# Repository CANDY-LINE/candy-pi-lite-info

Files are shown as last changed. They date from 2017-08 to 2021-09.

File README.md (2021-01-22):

# CANDY Pi Lite/CANDY Pi Lite+ 利用ガイド

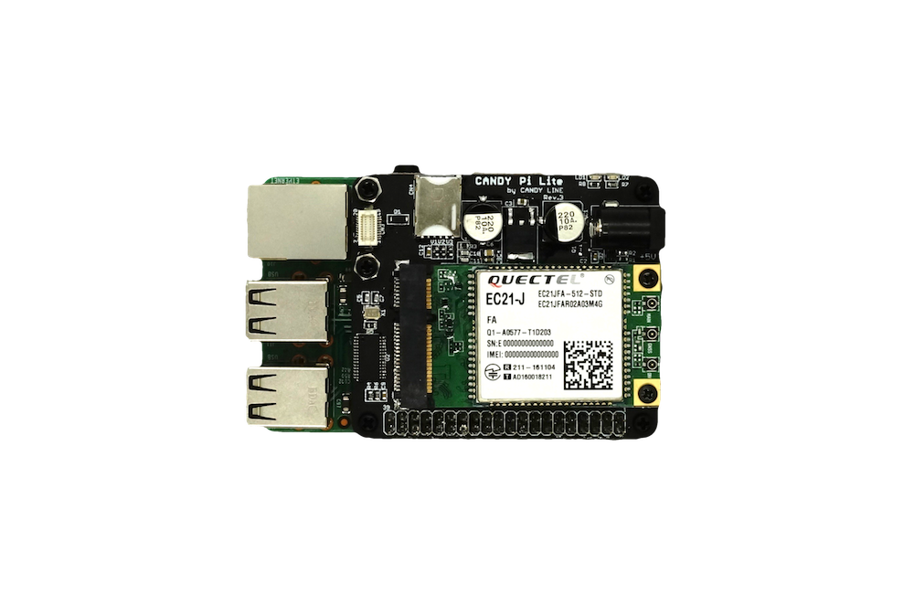
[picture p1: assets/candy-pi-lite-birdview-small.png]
CANDY Pi Lite with Raspberry Pi


CANDY Pi Lite及びCANDY Pi Lite+（以降、CANDY Pi Lite/+と表記します）は、Raspberry Pi（ラズベリーパイ、以下ラズパイ）や、ASUS Tinker Board(またはS)に取り付けて使用する3G/4G LTE通信ボードです。

CANDY Pi Lite 3Gモデルでは、3G回線をご利用頂けます（日本国外では2G及び3G回線をご利用いただけます）。CANDY Pi Lite LTEモデルでは、4G LTE回線をご利用頂けます。CANDY Pi Lite LTE-Mモデルでは、LTE-M回線、NB-IoT回線をご利用頂けます（日本国外では2G回線もご利用いただけます）。

CANDY Pi Lite+ Dモデルでは、NTTドコモの3G/4G LTE回線をご利用いただけます。CANDY Pi Lite+ Kモデルでは、au/KDDIの4G LTE回線とNTTドコモの3G/4G LTE回線をご利用いただけます。CANDY Pi Lite+ Sモデルでは、Softbankの3G/4G LTE回線をご利用いただけます。

CANDY Pi Lite+（マルチキャリア版）モデルでは、NTTドコモの3G/4G LTE回線、au/KDDIの4G LTE回線、それにSoftbankの3G/4G LTE回線をご利用いただけます。

本書では、CANDY Pi Lite/+の利用方法について、組立方法、利用開始までのセットアップ方法、また製品の外寸などのハードウェア情報を解説します。CANDY Pi Lite/+の活用方法やチュートリアルについては、[CANDY LINE Blog](https://candy-line.com/blog/) をご覧ください。

CANDY Pi Lite/+とそのサービスソフトウェア(candy-pi-lite)は、標準でPPPと呼ばれる方式で携帯電話ネットワークへ接続します。CANDY Pi Lite/+に搭載している通信モジュールは、Qualcomm Modem Interface(QMI)に対応しているため、USB接続で利用された場合は、QMI WWANを利用して通信を行うことも仕様上は可能です。しかし、今のところcandy-pi-lite サービスではQMI WWANに対応していません。

# 本書について

本書の内容は、随時加筆修正が行われます。最終更新日をご確認ください。

# 法律とライセンス

本書の著作権は、株式会社 CANDY LINEが保有しています。
本書の文章や写真等イメージデータの内容は、[CC-BY-NC-SA 4.0](https://creativecommons.org/licenses/by-nc-sa/4.0/)ライセンスの下で公開されます。

- 「CANDY Pi」、「CANDY LINE」は、株式会社 CANDY LINEの商標または登録商標です。
- 「Raspberry Pi」はRaspberry Pi財団の登録商標です。
- 「ASUS」は、ASUSTek Computerの登録商標です。
- 「Bluetooth」は、Bluetooth SIG,Inc.の登録商標です。
- 「EnOcean」は、EnOcean GmbHの登録商標です。
- その他の名称は、それぞれの所有者の商標または登録商標です。

その他、本書に記載されている製品名や会社名は、各企業の登録商標あるいは商標です。本文中では、「™」「®」マークが明記されていないことがあります。

# CANDY Pi Lite/+の使用について

⚠️CANDY Pi Lite/+の使用については、以下の点を注意してください。

1. **CANDY Pi Lite/+を水に濡らしたり、湿度の高いところで利用したり、あるいはまた結露が発生するような状況で利用しないようにしてください。**
1. **CANDY Pi Lite/+のDCジャックは、最大4Aまで対応しています。それより大きい電流容量のACアダプターを利用しないようにしてください。**
1. **CANDY Pi Lite/+のDCジャックは、初期ロットのASUS Tinker Board Sでは動作しないためお使いいただけません。2018年3月下旬以降に出荷されたASUS Tinker Board Sではご利用いただけます。**
1. **CANDY Pi Lite LTEモデルとCANDY Pi Lite+は、日本国内専用です。日本国外では利用してはいけません。**
1. **CANDY LINE®がインターネットで公開している情報以外の3G/4G LTE通信モデムに関する情報については、[リファレンス](references.md)ページ記載のメーカー情報をご覧ください。**

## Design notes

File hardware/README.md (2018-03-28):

# ハードウェア

ハードウェアに関する情報は、以下のページでご覧いただけます。

* [定格](rating.md)
* [寸法](size.md)
* [本体基板外観](appearance.md)
* [GPIOピンマッピング](gpio.md)
* [交換部品](supplies.md)
* [ASUS Tinker Board 付属のヒートシンクをお使いの方へ](atb-heatsink.md)

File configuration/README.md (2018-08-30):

# 設定変更

candy-pi-lite サービスについて以下の設定について説明します。

* [LED設定](led.md)
* [APN設定](apn.md)
* [モバイルネットワークへの接続設定](connection.md)
* [プリセットされたAPNの一覧](apn-list.md)
* [GNSS/GPSの使用](gnss.md)
* [自動時刻調整](rtc.md)
* [有線LAN固定IP設定](ether-static-ip.md)
* [ハードウェアWatchdog](hw-watchdog.md)
* [EnOcean USBゲートウェイの利用](enocean.md)
* [デフォルトゲートウェイ調整機能のOFF](default-gw-adjuster.md)
* [シリアルポートの種別選択指定](serial-port-selector.md)
* [ufwを利用してグローバルIP経由のPingを拒否する方法](ufw-icmp.md)
* [RaspberryPi(Raspbian)でモバイルルーターとして使用する設定](rpi-router.md)
* [利用可能なシリアルポートについて](serialports.md)
* [IP到達確認監視](ip-reachability-test.md)

また、CANDY REDの下記設定方法についても説明します。

* [ノードの設定](candy-red-nodes.md)

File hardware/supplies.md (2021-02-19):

<!-- toc -->

# 追加部品、交換部品

## USBケーブル

USB接続をご利用の場合、ご利用者の方にUSBケーブルをご用意いただく必要があります。USBケーブルは電源を供給する必要はないため、多くの場合コネクターの形状があっていれば現在流通するケーブルを利用可能です。仕様上はUSB2.0の規格を満たしていればそれ以外の要件はありません。

個人利用であれば、充電専用ではないものであれば100円ショップのものでも利用可能ですし、大量に使用する場合は、下記のような商品をご利用ください。

- [USBケーブル（秋月電子通商）](http://akizukidenshi.com/catalog/c/cusbcable/)
- [USBケーブル（せんごくネット通販）](https://www.sengoku.co.jp/mod/sgk_cart/search.php?cid=3684)

ご購入の際は、USBケーブルのコネクターの形状にご注意ください。

- USBタイプAオス・・・「Raspberry Pi Model A+/Model B+/Pi2/Pi3」「ASUS Tinker Board」側
- マイクロUSB(マイクロB)オス・・・「CANDY Pi Lite」「CANDY Pi Lite+」接続側（「なにつなぐ？」ボード側）、「Raspberry Pi Zero/W/WH」側

\* Raspberry Pi Zero/W/WH」をご利用の場合、希望のケーブルがないときは変換コネクターもご利用いただけます。

## アンテナとSMA-U.FL変換ケーブルセット

「CANDY Pi Lite 3G」、「CANDY Pi Lite LTE」、「CANDY Pi Lite+ D」、「CANDY Pi Lite+ S」、「CANDY Pi Lite+ K」に付属しているアンテナとケーブルは、ソラコム社のコンソールから購入が可能です。

- メーカー：Hanwool Technology
- 型名：HW-MULTI-GA-RSMA
- 紹介サイト：https://soracom.jp/products/module/

アカウントを作成してから（無料）、管理コンソールの画面を通じて購入が可能です。
購入方法の詳細については、「[お問い合わせ](https://soracom.jp/contact/)」ページより直接ソラコム社へお問い合わせください。

## SMA-U.FL変換ケーブル

通信モジュールとアンテナとを取り付ける同軸ケーブルには、SMAとU.FLコネクターの変換ケーブルを利用しています。
このケーブルはSMAの根元部分や、U.FLの根元部分は取り外しのタイミングで破損しやすいため、取り扱いにはご注意ください。

ケーブルの取り外しの際には、指だけで取り外すとコネクターの根元を破損しやすいため、先がL字型のピンセットのようなものを使って以下の写真のようにしっかり掴んでから垂直に引っ張るようにすると安全に取り外しができます。

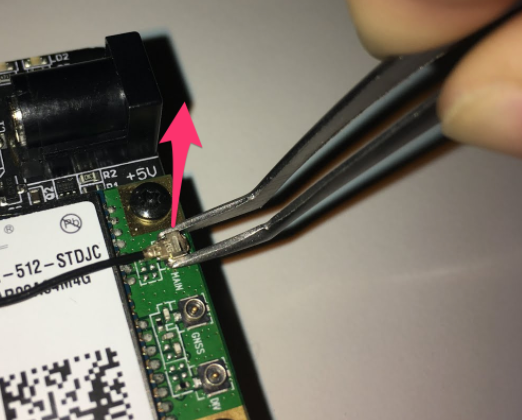
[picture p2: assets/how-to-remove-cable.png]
ケーブル取り外し


なおもし以下の写真のように破損してしまった場合は、下記の商品にて代用可能です（SMAコネクターの部分がリバースタイプではないもの）。

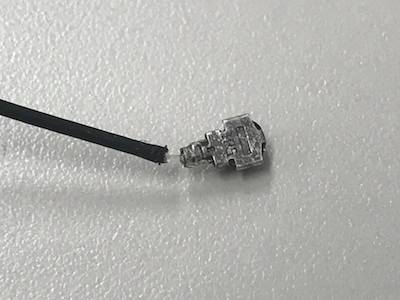
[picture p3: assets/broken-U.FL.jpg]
U.FL破損部分


- [SMA-U.FL変換ケーブル 長さ約10cm(せんごくネット通販)](http://www.sengoku.co.jp/mod/sgk_cart/detail.php?code=2DC5-UHLE)
- [RS Pro, 同軸ケーブルアセンブリ 150mm(アールエスコンポーネンツ)）](http://jp.rs-online.com/web/p/coaxial-cable-assemblies/7942897/)

## GNSS/GPSアンテナ・ケーブル

「CANDY Pi Lite 3G」と「CANDY Pi Lite+」については、GNSSモジュールが搭載されています。このモジュールを使うためには、専用のアンテナをご利用ください。付属のアンテナでも利用可能ですがケーブル長がほぼないため、常にラズパイを屋外か屋外近くに配置する必要があり実用的ではありません。

SMAコネクター接続のGNSS/GPSアンテナをご利用いただくとケーブルの取り回しがしやすく便利です。
なお、同軸ケーブルについては、付属品では足りない場合は上記SMAケーブルをご利用ください。

## DCジャック用ACアダプター

「CANDY Pi Lite 3G」、「CANDY Pi Lite LTE」や「CANDY Pi Lite+」に搭載されているDCジャックは、以下の規格に合致したACアダプターを利用することが可能です。

- 出力電圧：5V
- 出力電流：3Aまたは4A（Raspbrry PiやASUS Tinker Boardに取り付ける機器も加味してご検討ください）
- プラグ形状：DCプラグ・ジャック
- プラグ寸法：内径：φ2.1mm、外径：φ5.5mm
- 極性：センタープラス

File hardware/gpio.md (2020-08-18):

<!-- toc -->

# GPIOピンマッピング

CANDY Pi Lite/CANDY Pi Lite+は以下のGPIOピンを使用しています。

GPIOをお使いの場合は、下記以外のピンをご利用ください。

| GPIO HW Pin#  | RPi GPIO(40pins) | ASUS Tinker Board(またはS) | UC20/EC21 | CANDY Pi Lite |
| --- | --- | --- | --- | --- |
| PIN 38 |  20 (OUT) |  187 (OUT, GP6A3) | PERESET | RESET |
| PIN 32 |  12 (OUT) |  239 (OUT, GP7C7) | W_DISABLE | - |
| PIN 19 |  10 (SPI0_MOSI)  |  257 (SPI2TXD, GP8B1)  | - | SI |
| PIN 21 | 9 (SPI0_MISO)  |  256 (SPI2RXD, GP8B0)  | - | SO |
| PIN 23 |  11 (SPI0_SCLK)  |  254 (SPI2CLK, GP8A6)  | - | SCLK |
| PIN 26 | 7 (SPI0_CE1) |  251 (SPI2CSN1, GP8A3) | - | CS |
| PIN 40 |  21 (IRQ) |  188 (IRQ, GP6A4) | - | IRQ |
| - | - | - | LED_WWAN |  LED1 (GREEN) |
| PIN  7 | 4 (OUT) |  17 (OUT, GP0C1) | - |  LED2 (ORANGE)|

## SPI接続について

本製品は、ラズパイやASUS Tinker Boardの40ピンGPIOにあるSPIを使用しています。ラズパイでは、`SPI0`を、ATBでは`SPI2`を使用します。ラズパイでもASUS Tinker Boardでもチップセレクト1(`CE1`/`CS1`)を物理的に常に占有していますので、SPIをお使いになる場合は、チップセレクト0(`CE0`/`CS0`)のピンをご利用ください。`CE1`/`CS1`を利用することはできませんのでご注意ください。

Raspberry Pi B+以降で使用できる`SPI1`については、残念ながら本製品の使用するGPIOピンが一部重複しているため使用できません。

ASUS Tinker Boardの`SPI0`については、ピンが重複していないため利用可能です。

## LED2（オレンジ）

candy-pi-liteの動作状況を表します。一定パターンで点滅を繰り返しているときは、携帯電話ネットワークに接続されています。消灯の場合は、携帯電話ネットワークへ接続できていません。

## PERST（リセット）

PERSTをlowに落とすと、3G/LTE通信モジュールとCANDY Pi Lite上のSC16IS75xのチップの両方をリセットすることができます。lowに落とす時間は、UC20/EC21の技術資料(Hardware Design)によれば、150~460msと決められていますが、概ね1秒程度でもリセット可能です。

candy-pi-lite サービスでは、サービス起動時にモデムのリセットを常に行なっていますので、通常の利用であれば利用者の方が明示的にリセットを行う必要はありません。

## W_DISABLE（無線OFF）

W_DISABLEピンをlowに落とすと、3G/LTE通信モジュールの無線動作を止めることができます。ただし、この操作をして無線を停止した場合、candy-pi-lite サービスが接続できないことを検出するまでおよそ2~3分かかります。

通常は、candy-pi-lite サービスの停止によって通信を停止するようにしてください。

なお、W_DISABLEピンをhighに設定し直したとしても、通信が自動的に復帰することはありません。明示的に[candy-pi-lite サービスを再起動](/service/restart.md)してください。また、無線接続を再開する場合は、W_DISABLEピンをhighに設定し直す必要がありますが、candy-pi-lite サービスは自動的に再設定を行いますので、利用者の方がW_DISABLEピンをhighに戻す必要はありません。

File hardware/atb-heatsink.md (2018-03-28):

<!-- toc -->

# ASUS Tinker Board 付属のヒートシンクをお使いの方へ

ASUS Tinker BoardやASUS Tinker Board Sには、標準でヒートシンクが付属しています。このヒートシンクを取り付けた時、CANDY Pi Lite付属のスペーサーでは高さが足りず、CANDY Pi Liteの本体基板と接触します。このため、以下の対応をお願いいたします。

* ネジ径2.6ミリ、長さ12ミリまたはそれより長いスペーサー（例えば、[樹脂スペーサー](http://www.hirosugi-net.co.jp/shop/g/g4210/)や[金属スペーサー](http://www.hirosugi-net.co.jp/shop/g/g416/)など）をご購入いただく（付属品は長さ11ミリです）。

上記対応により、CANDY Pi Lite取り付け時にGPIOピン接触部分が1ミリ浮き上がりますが動作に支障はございません。

## スペーサー配布プログラムにつきまして

CANDY LINEでは、ユーザー登録をされた方でご希望の方には、一定条件を満たすと2018年3月31日（日本時間）まで真鍮製12ミリスペーサー（1台あたり4本）を無償で郵送するプログラムを実施します。詳しい適用条件は、[こちらの案内](https://forums.candy-line.io/t/topic/128)をご覧ください。

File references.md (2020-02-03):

# リファレンス

CANDY Pi Liteに搭載されている3G/LTE通信モジュールの技術情報については以下の情報を参照してください。通信モジュールそのものに関する質問等は、[Quectel Wireless Solutions社の技術フォーラム](https://forums.quectel.com/)をご利用ください。

- [Quectel Wireless Solutions UC20 仕様](http://www.quectel.com/product/uc20minipcIe.htm)
- [Quectel Wireless Solutions EC21 仕様](http://www.quectel.com/product/ec21minipcIe.htm)
- [Quectel Wireless Solutions EC25 仕様](http://www.quectel.com/product/ec25minipcIe.htm)
- [Quectel Wireless Solutions BG96 仕様](https://www.quectel.com/product/bg96.htm)
- [Quectel Wireless Solutions UC20 技術ドキュメントのダウンロード](http://www.quectel.com/support/downloadb/TechnicalDocuments.htm?keys=UC20)
- [Quectel Wireless Solutions EC21 技術ドキュメントのダウンロード](http://www.quectel.com/support/downloadb/TechnicalDocuments.htm?keys=EC21)
- [Quectel Wireless Solutions EC25 技術ドキュメントのダウンロード](http://www.quectel.com/support/downloadb/TechnicalDocuments.htm?keys=EC25)
- [Quectel Wireless Solutions BG96 技術ドキュメントのダウンロード](http://www.quectel.com/support/downloadb/TechnicalDocuments.htm?keys=BG96)

**ご注意：上記のうち、技術ドキュメントのダウンロードにはユーザー登録が必要となります。ユーザー登録の案内はPDFダウロード時に表示されます。**

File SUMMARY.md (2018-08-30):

# Summary

* [はじめに](README.md)
* [ハードウェア情報](hardware/README.md)
  * [定格](hardware/rating.md)
  * [寸法](hardware/size.md)
  * [本体基板外観](hardware/appearance.md)
  * [GPIOピンマッピング](hardware/gpio.md)
  * [交換部品](hardware/supplies.md)
  * [ASUS Tinker Board 付属のヒートシンクをお使いの方へ](hardware/atb-heatsink.md)
* [セットアップの仕方](setup/README.md)
  * [CANDY Pi Lite+の組み立て](setup/assemble-plus.md)
  * [CANDY Pi Lite 3Gモデルの組み立て](setup/assemble-3g.md)
  * [CANDY Pi Lite LTEモデルの組み立て](setup/assemble-lte.md)
  * [低速通信を利用する場合の準備](setup/uart.md)
  * [USB接続を利用する場合の準備](setup/usb.md)
  * [OSイメージファイルを利用したセットアップ](setup/etcher.md)
  * [既存SDカードを利用したセットアップ](setup/terminal.md)
  * [インストールエラー](setup/installation-errors.md)
  * [CANDY REDへのブラウザー接続](setup/browsing-candy-red.md)
  * [CANDY RED単体のインストール](setup/candy-red.md)
  * [Node-REDからの移行方法](setup/node-red-migration.md)
* [バージョンアップの仕方](upgrade/README.md)
  * [candy-pi-lite サービスのアップデート](upgrade/candy-pi-lite-service.md)
  * [CANDY REDのアップデート](upgrade/candy-red.md)
* [アンインストールの仕方](uninstallation/README.md)
  * [candy-pi-lite サービスのアンインストール](uninstallation/candy-pi-lite-service.md)
  * [CANDY REDのアンインストール](uninstallation/candy-red.md)
* [candy-pi-lite サービスの制御](service/README.md)
  * [起動](service/start.md)
  * [停止](service/stop.md)
  * [再起動](service/restart.md)
  * [ログ表示](service/cat.md)
* [CANDY Pi Lite/+ 設定変更](configuration/README.md)
  * [LED設定](configuration/led.md)
  * [APN設定](configuration/apn.md)
  * [モバイルネットワークへの接続設定](configuration/connection.md)
  * [プリセットされたAPNの一覧](configuration/apn-list.md)
  * [GNSS/GPSの使用](configuration/gnss.md)
  * [自動時刻調整](configuration/rtc.md)
  * [有線LAN固定IP設定](configuration/ether-static-ip.md)
  * [ハードウェアWatchdog](configuration/hw-watchdog.md)
  * [EnOcean USBゲートウェイの利用](configuration/enocean.md)
  * [デフォルトゲートウェイ調整機能のOFF](configuration/default-gw-adjuster.md)
  * [シリアルポートの種別選択指定](configuration/serial-port-selector.md)
  * [ufwを利用してグローバルIP経由のPingを拒否する方法](configuration/ufw-icmp.md)
  * [RaspberryPi(Raspbian)でモバイルルーターとして使用する設定](configuration/rpi-router.md)
  * [利用可能なシリアルポートについて](configuration/serialports.md)
  * [IP到達確認監視](configuration/ip-reachability-test.md)
* [CANDY RED設定変更](configuration/README.md)
  * [ノードの設定](configuration/candy-red-nodes.md)
* [コマンドラインツール](cli/README.md)
  * [SIMカード認識状態の表示](/cli/sim.md)
  * [ネットワーク状態の表示](/cli/network.md)
  * [通信モジュール情報の表示](/cli/modem.md)
  * [GNSSの制御](/cli/gnss.md)
  * [モバイルネットワーク接続の制御](/cli/connection.md)
* [そのほかの利用方法](/misc/README.md)
  * [USB拡張ボードの使い方](/misc/usbboard.md)
* [リファレンス](references.md)
* [トラブルシューティング](troubleshooting.md)

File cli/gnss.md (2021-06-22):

# GNSS/GPSの制御

## GPSの起動

初期状態では、GPSの機能は停止状態になっています。GPSを使うときは、GPSの起動を明示的に行う必要があります。
OS起動時に常に起動させたい時は、[こちらの「インストールした後にGNSS自動起動設定を変更する方法」](/configuration/gnss.md)をご覧ください。

```bash
$ sudo candy gnss start [オプション]
```

CANDY Pi Lite/CANDY Pi Lite+とラズパイまたはASUS Tinker Boardを接続している時は、一度起動すると明示的に停止させるまで起動し続けます。ただし、GNSS電波が不通の状態が続く場合は停止することがあります。

[オプション]には、以下のものを使用することができます。
（** QZSSについては、👉[`candy-pi-lite-service v6.4.0`](https://forums.candy-line.io/t/candy-pi-lite-v6-4-0)以降で対応しています ** ）

- `-q`または`--qzss` ... QZSS（みちびき）を有効にします。同時に、GLONASSと北斗も有効になります（これら2つは無効にできません）
- `-a`または`--all` ... QZSS（みちびき）を有効にします。同時に、Galileo、GLONASS、北斗も有効になります（これら3つは無効にできません）
- `-s`または`--suspend` ... UART接続で通信中の場合、通信を一時的に中断します
- `-r`または`--resume` ... UART接続で通信を中断している場合、再開します

** ご注意 **

* QZSS（みちびき）は、CANDY Pi Lite+シリーズのみ利用可能です。

UART接続（USB接続なし）で通信中の場合は、以下のように`--suspend --resume`をつけてください。

```bash
$ sudo candy gnss start --suspend --resume
```

これによって、一時的に接続を中断し、GPSを起動してから接続を再開します。接続が停止する時間は、電波環境が良ければ4G/LTEであれば6秒前後、3Gでは10秒前後となります。

## GPSの停止

GPSの動作を止める場合は、以下のコマンドを実行します。

```bash
$ sudo candy gnss stop
```

UART接続（USB接続なし）で通信中の場合は、以下のように`--suspend --resume`をつけてください。

```bash
$ sudo candy gnss stop --suspend --resume
```

## GPSの起動状態確認

GPSの起動状態を見るには、以下のコマンドを実行します。

```bash
$ sudo candy gnss status
```

UART接続（USB接続なし）で通信中の場合は、以下のように`--suspend --resume`をつけてください。

```bash
$ sudo candy gnss status --suspend --resume
```

結果は、以下のようなJSON形式の文字列が返ります。

```
{
  "session": "stopped",
  "qzss": "enabled"
}
```

- `session` ... GPSが起動中の場合は`started`、そうでない場合は`stopped`となります
- `qzss` ... QZSSが有効な場合は`enabled`、無効な場合は`disabled`、利用できない場合は`N/A`となります

## コマンドによるGPSの位置取得

GPSの位置情報をコマンドラインから取得することができます。

```bash
$ sudo candy gnss locate
```

結果は、以下のようなJSON形式の文字列が返ります。

```
{
  "timestamp": "2018-05-23T04:26:44.000Z",
  "latitude": 35.00000,
  "longitude": 139.00000,
  "altitude": 54.8,
  "cog": 132.3,
  "spkm": 0.0,
  "spkn": 0.0,
  "nsat": 7,
  "hdop": 0.9,
  "fix": "2D"
}
```

- `timestamp` ... ISO8601フォーマットの日付(UTC)
- `latitude` ... 緯度 (°)
- `longitude` ... 経度 (°)
- `altitude` ... 高度 (m)
- `cog` ... 進行方向(真北からの角度)
- `spkm` ... 対地速度(km/h)
- `spkn` ... 対地速度(knots)
- `nsat` ... 受信衛星数
- `hdop` ... 水平位置精度劣化度(0.5~99.9)
- `fix` ... GNSS測位モード(2Dまたは3D)

UART接続（USB接続なし）で通信中の場合は、以下のように`--suspend --resume`をつけてください。

```bash
$ sudo candy gnss locate --suspend --resume
```

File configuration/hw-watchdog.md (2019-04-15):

<!-- toc -->

# ハードウェアWatchdog

**👉 ~~本機能は、ラズパイ専用です。ASUS Tinker Board(またはS)ではご利用になれません~~ [`candy-pi-lite-service v1.6.0`](https://forums.candy-line.io/t/v4-0-0)以降では、ASUS Tinker Board(またはS)に対応しています**

**👉[`candy-pi-lite-service v1.6.0`](https://forums.candy-line.io/t/v1-6-0/55)以降で対応しています**

## 概要

Raspberry PiやASUS Tinker Board(またはS)には、ハードウェアの仕組みとしてシステム無応答を検知したときに自動的に再起動をする仕組みを備えています。しかし、通常その機能をは無効にされており、必要なときにだけ有効にするようになっています。

この機能を利用するために特別なソフトウェアのインストールは不要です。ただし、Raspberry Piをお使いの場合は、OSはRaspbian Stretch 以降でなければなりません。

もし意図せずにハードウェアWatchdogを有効にしてしまっても、以下に記載する設定無効化方法を実施することにより無効にすることが可能です。

## 設定方法

candy-pi-liteサービスをインストールするときに、`ENABLE_WATCHDOG=1`を指定してください。手動で設定したい場合は、こちらの[投稿](https://www.raspberrypi.org/forums/viewtopic.php?t=175432#p1119436)を参照してください。

## 設定確認方法

フォークボムと呼ばれる下記のコマンドを実行するとシステム再起動を確認することができます。ただし、ハードウェアWatchdogを設定せずにコマンドを実行すると、著しく動作が遅くなり制御不能になったりするため電源をOFFにする以外に方法はなくなりますのでご注意ください。

```
:(){ :|: & };:
```

## 設定無効化方法【Raspberry Pi】

ハードウェアWatchdogの設定を無効にするには、まず`/boot/config.txt`ファイルの以下の内容を見つけてください。
あるいは、WindowsやMacなどのコンピューターでもマイクロSDカードを差し込んでからその中身を見て「`config.txt`」をテキストエディターで開いてみてください。

```
dtparam=watchdog=on
```

続いて上記の値を以下のように変更します。

```
dtparam=watchdog=off
```

ファイルを保存してRaspbianを再起動させてください。別のコンピューターで作業した場合は、このマイクロSDカードをRaspberry Piに差し込んで、起動させてください。

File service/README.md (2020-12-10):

# candy-pi-lite サービスの制御

candy-pi-lite サービスの動作をターミナルからコマンドラインで制御することができます。
通常、サービスの制御を行う必要はありませんが、アプリケーション開発や動作検証時には役立つことがあります。

* [candy-pi-lite サービスの起動](start.md)
* [candy-pi-lite サービスの停止](stop.md)
* [candy-pi-lite サービスの再起動](restart.md)
* [candy-pi-lite サービスのログ表示](cat.md)
* [candy-pi-lite サービスの有効化・無効化](enable-disable.md)

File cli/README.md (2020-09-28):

# コマンドラインツール

candy-pi-lite サービスをインストールすると、`candy`コマンドをターミナルから利用することができます。
このコマンドを使うと以下の機能を利用することができます。ただし、APN設定については、`candy`コマンドを利用しても設定は反映されません。[APN設定](/configuration/apn.md)のページをご覧になり、そちらに記載の方法でAPNを設定してください。

  * [SIMカード認識状態の表示](sim.md)
  * [ネットワーク状態の表示](network.md)
  * [通信モジュール情報の表示](modem.md)
  * [GNSSの制御](gnss.md)
  * [モバイルネットワーク接続の制御](connection.md)

## コマンドラインご利用上の注意

`candy`コマンドを実行するには、candy-pi-lite サービスが動作していなければなりません。動作していない場合は、以下のようなエラーメッセージが表示されます。

```
[ERROR] CANDY Board Service isn't running
```

このような場合は、[candy-pi-lite サービスの起動](/service/start.md)をおこなってください。すでに起動処理が進行している時は、完了までリトライするようにしてください。

また、CANDY Pi Liteが携帯電話ネットワークに接続されている場合は、次のようなメッセージが出ることがあります。

```
"Modem is not ready"
```

これは、コマンドラインツールと通信モジュールとの間のシリアル通信が、携帯電話ネットワークへのIP通信と同一経路を利用しているため、携帯電話ネットワークへのIP通信を行っている最中には`candy`コマンドの実行を行うことができないということによるエラーメッセージです。この場合は、`-s -r`と言う接続の一時停止と復旧のオプションをつけてコマンドを実行することによりスムーズにコマンドを実行しつつ接続状態を維持することが可能です。

## プログラムから使用する場合について

### コマンド実行結果文字列

`candy`コマンドをプログラムから使用すると結果文字列に文字色をつけるエスケープシーケンスが入った文字列で返ってきます。これを防ぐには`NO_COLOR=1`の環境変数を実行プロセスに渡すようにしてください。

### 接続状態を調べるには

`candy`コマンドを利用すると接続状態を確認することができます。これを利用して、プログラム上で接続状態がオンラインになってから次の処理を行うなどの動きを実現可能です。
注意点としては、

1. 接続状態確認には`candy connection status`を使用すること（`-r -s`のオプションは常に不要です）。
1. 結果コードが`0`以外の場合は、時間を置いてリトライすること（サービスが起動中の場合は結果コードが0以外のコードになります）。
1. `NO_COLOR=1`の環境変数をつけてコマンドを実行すること（前述の通り、プログラム処理にとっては余計な文字列を排除するためのものです）。
1. `candy`コマンドは特権ユーザーで実行すること。

判定方法は、以下の通りです。`NO_COLOR=1`の環境変数をつけていない場合、文字列一致ができませんのでご注意ください。
- 結果の文字列が`OFFLINE`または結果コードが0以外の場合は、接続できていません。
- 結果の文字列が`ONLINE`の場合は、接続できています。
- 結果コードが0以外の場合、文字列には`[ERROR] CANDY Board Service isn't running`が入ります。

### CANDY Pi Liteサービスのソフトウェアバージョンを調べるには

`candy service version`を実行すると、CANDY Pi Liteソフトウェアのバージョンを調べることができます。

実施例）
```
$ sudo candy service version
{
  "version": "10.0.1"
}
```

ただし、サービスが起動していない場合は、次のように`CANDY Board Service isn't running`とメッセージが表示されます。
その場合はサービスが起動するまで待ってから再度コマンドを実行してください。

```
$ sudo candy service version
[ERROR] CANDY Board Service isn't running
```

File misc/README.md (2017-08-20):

# そのほかの利用方法

CANDY Pi Liteに付属するUSB拡張ボードを使うと、3G/LTE通信以外の機能も利用することができます。
通常は、このボードはUSB接続のためのボードとして利用しますが、それ以外の使い方も説明します。

* [USB拡張ボードの使い方](usbboard.md)

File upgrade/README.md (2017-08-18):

# バージョンアップの仕方

CANDY Pi Liteをセットアップした際にインストールされたソフトウェアは、以下の方法でバージョンアップを行うことができます。

* [candy-pi-lite サービスのバージョンアップ](candy-pi-lite-service.md)
* [CANDY REDのバージョンアップ](candy-red.md)

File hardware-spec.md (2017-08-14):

# ハードウェア仕様

GitBook allows you to organize your book into chapters, each chapter is stored in a separate file like this one.

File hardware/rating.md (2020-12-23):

<!-- toc -->

# 定格

** 👉　製品の外観や仕様は、製品改善により予告なく変更されることがあります。 **

## CANDY Pi Lite 3Gモデル

| 項目 |  最小 | 標準 | 最大 | 単位 |
| --- | ----- | --- | ---- | --- |
|  電源電圧(DC) | 4.75 |  5  | 5.25 | V |
|  消費電流*1 | 37 |  -  | 601  | mA  |
|  供給可能電流 | 0 |  -  | 4 | A |
|  動作温度範囲(rev.3)*2 | 0 | 25  | 80 | ℃ |
|  動作温度範囲(rev.8以降)*2 | -25  | 25  | 70 | ℃ |

\*1 最小は標準使用時のアイドル状態時、GPRS使用時の最大は683mA<br>
\*2 温度は周囲温度(Ta)、ただし結露なきこと

### 3G通信モジュール性能

| 項目 | 説明 |
| --- | --- |
| 機種 | Quectel UC20-G（本書ではUC20と記載します） |
| 対応周波数・バンド | UMTS：800/850/900/1900/2100MHz<br>GSM/EDGE：850/900/1800/1900MHz（日本国外のみ）|
| 通信速度 | ・標準使用時：下り上り共に最大約460Kbps<br>・付属USB拡張ボード使用時：下り最大14.4Mbps／上り最大5.76Mbps<br>※いずれの通信速度も技術規格上の最大値であり、実使用速度を示すものではありません |
| GNSS/GPS | 対応<br>GNSSのコネクターにアンテナを取り付けてご利用いただけます |
| 利用可能な地域 | 日本国内、及び日本国外のUMTS/GSM/EDGEエリア* |

\* ただしCANDY LINEでは、日本国内のみ動作を確認しております

## CANDY Pi Lite LTEモデル

| 項目 |  最小 | 標準 | 最大 | 単位 |
| --- | ----- | --- | ---- | --- |
|  電源電圧(DC) | 4.75 |  5  | 5.25 | V |
|  消費電流*1 | 37 |  -  | 976  | mA  |
|  供給可能電流 | 0 |  -  | 4 | A |
|  動作温度範囲(rev.3)*2 | 0 | 25  | 80 | ℃ |
|  動作温度範囲(rev.8以降)*2 | -25  | 25  | 70 | ℃ |

\*1 最小は標準使用時のアイドル状態時<br>
\*2 温度は周囲温度(Ta)、ただし結露なきこと

### 4G LTE通信モジュール性能

| 項目 | 説明 |
| --- | --- |
| 機種 | Quectel EC21-J（本書ではEC21と記載します） |
| 対応周波数・バンド | FDD-LTE:B1/B3/B8/B18/B19/B26 |
| 通信速度 | ・標準使用時：下り上り共に最大約460Kbps<br>・付属USB拡張ボード使用時：下り最大10Mbps／上り最大5Mbps<br>※いずれの通信速度も技術規格上の最大値であり、実使用速度を示すものではありません |
| GNSS/GPS | 非対応 |
| 利用可能な地域 | 日本国内 |

## CANDY Pi Lite LTE-Mモデル

| 項目 |  最小 | 標準 | 最大 | 単位 |
| --- | ----- | --- | ---- | --- |
|  電源電圧(DC) | 4.75 |  5  | 5.25 | V |
|  消費電流*1 | 24 |  -  | 331 (Cat M1), 474 (Cat NB1)| mA  |
|  供給可能電流 | 0 |  -  | 4 | A |
|  動作温度範囲*2 | -25  | 25  | 70 | ℃ |

\*1 最小は標準使用時のアイドル状態時<br>
\*2 温度は周囲温度(Ta)、ただし結露なきこと

### LTE-M/NB-IoT通信モジュール性能

| 項目 | 説明 |
| --- | --- |
| 機種 | Quectel BG96-G（本書ではBG96と記載します） |
| 対応周波数・バンド | Cat M1/Cat NB1:[LTE FDD: B1/B2/B3/B4/B5/B8/B12/B13/B18/B19/B20/B21/B26/B28] [LTE TDD: B39 (For Cat M1 Only) *1|
| 通信速度 | ・標準使用時：下り上り共に最大約460Kbps<br>・付属USB拡張ボード使用時：下り上り共に最大約460Kbps<br>※いずれの通信速度も技術規格上の最大値であり、実使用速度を示すものではありません |
| GNSS/GPS | 対応<br>GNSSのコネクターにアンテナを取り付けてご利用いただけます |
| 利用可能な地域 | 日本国内、及び日本国外のLTE Cat M1/LTE Cat NB1/EDGEエリア *2 |

\*1 KDDI回線は、Cat M1のみ利用可能。docomoの認証は現時点ではCat M1のみ。
\*2 ただしCANDY LINEでは、日本国内のみ動作を確認しております

## CANDY Pi Lite+モデル（NTTドコモ、au/KDDI、ソフトバンク向け共通）

| 項目 |  最小 | 標準 | 最大 | 単位 |
| --- | ----- | --- | ---- | --- |
|  電源電圧(DC) | 4.75 |  5  | 5.25 | V |
|  消費電流*1 | 33 |  -  | 991 | mA  |
|  供給可能電流 | 0 |  -  | 4 | A |
|  動作温度範囲*2  | -25 | 25  | 70 | ℃ |

\*1 最小は標準使用時のアイドル状態時<br>
\*2 温度は周囲温度(Ta)、ただし結露なきこと

### 3G/4G LTE通信モジュール性能(NTTドコモ向けモデル)

| 項目 | 説明 |
| --- | --- |
| 機種 | Quectel EC25-J-FA-DCM（本書ではEC25と記載します） |
| 対応周波数・バンド | 4G/LTE:B1/B3/B19 3G:B1/B6/B19 |
| 通信速度 | ・標準使用時：下り上り共に最大約460Kbps<br>・付属USB拡張ボード使用時：下り最大150Mbps／上り最大50Mbps<br>※いずれの通信速度も技術規格上の最大値であり、実使用速度を示すものではありません |
| GNSS/GPS | 対応 |
| 利用可能な地域 | 日本国内 |

### 3G/4G LTE通信モジュール性能(au/KDDI向けモデル)

| 項目 | 説明 |
| --- | --- |
| 機種 | Quectel EC25-J-FA-KDI（本書ではEC25と記載します） |
| 対応周波数・バンド | 4G/LTE:B1/B11/B18（au/KDDIネットワークの場合）、B1/B3/B19（NTTドコモネットワークの場合） 3G:B1/B6/B19（NTTドコモネットワークのみ対応） |
| 通信速度 | ・標準使用時：下り上り共に最大約460Kbps<br>・付属USB拡張ボード使用時：下り最大150Mbps／上り最大50Mbps<br>※いずれの通信速度も技術規格上の最大値であり、実使用速度を示すものではありません |
| GNSS/GPS | 対応 |
| 利用可能な地域 | 日本国内 |

### 3G/4G LTE通信モジュール性能(ソフトバンク向けモデル)

| 項目 | 説明 |
| --- | --- |
| 機種 | Quectel EC25-J-FA-SBK（本書ではEC25と記載します） |
| 対応周波数・バンド | 4G/LTE:B1/B3/B8/B41 3G:B1/B8 |
| 通信速度 | ・標準使用時：下り上り共に最大約460Kbps<br>・付属USB拡張ボード使用時：下り最大150Mbps／上り最大50Mbps<br>※いずれの通信速度も技術規格上の最大値であり、実使用速度を示すものではありません |
| GNSS/GPS | 対応 |
| 利用可能な地域 | 日本国内 |

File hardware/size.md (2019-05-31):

<!-- toc -->

# 寸法

## CANDY Pi Lite/CANDY Pi Lite+本体寸法

- [CAD図面（DXF形式）ダウンロード](/assets/candy-pi-lite-dimension.dxf) ※3DCG用のモデルではありません
- [3Dモデル（STEP形式）ダウンロード](/assets/candy-pi-lite-dimension.stp) ※各種ブラウザービューワー([Autodesk® Viewer](https://viewer.autodesk.com/), [STP Viewer](https://3d-viewers.com/step-viewer.html) など)でも3Dモデルを閲覧できます

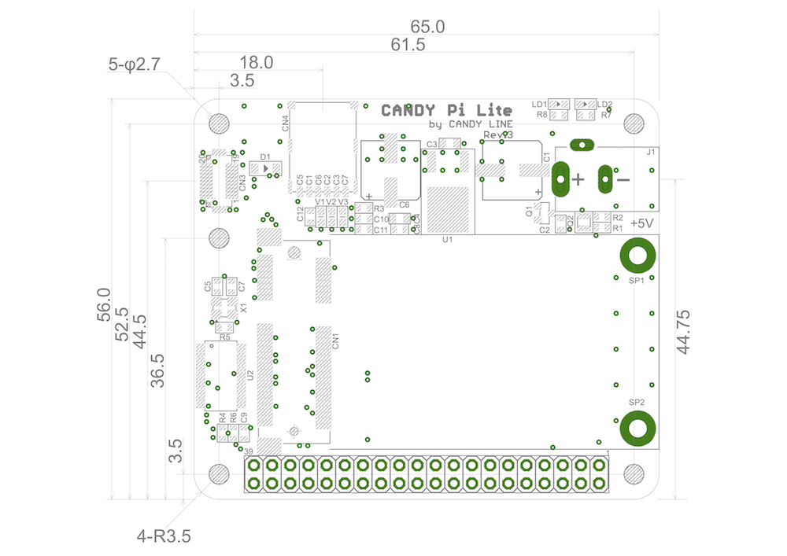
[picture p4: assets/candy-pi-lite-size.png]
CANDY Pi Lite/CANDY Pi Lite+ 平面


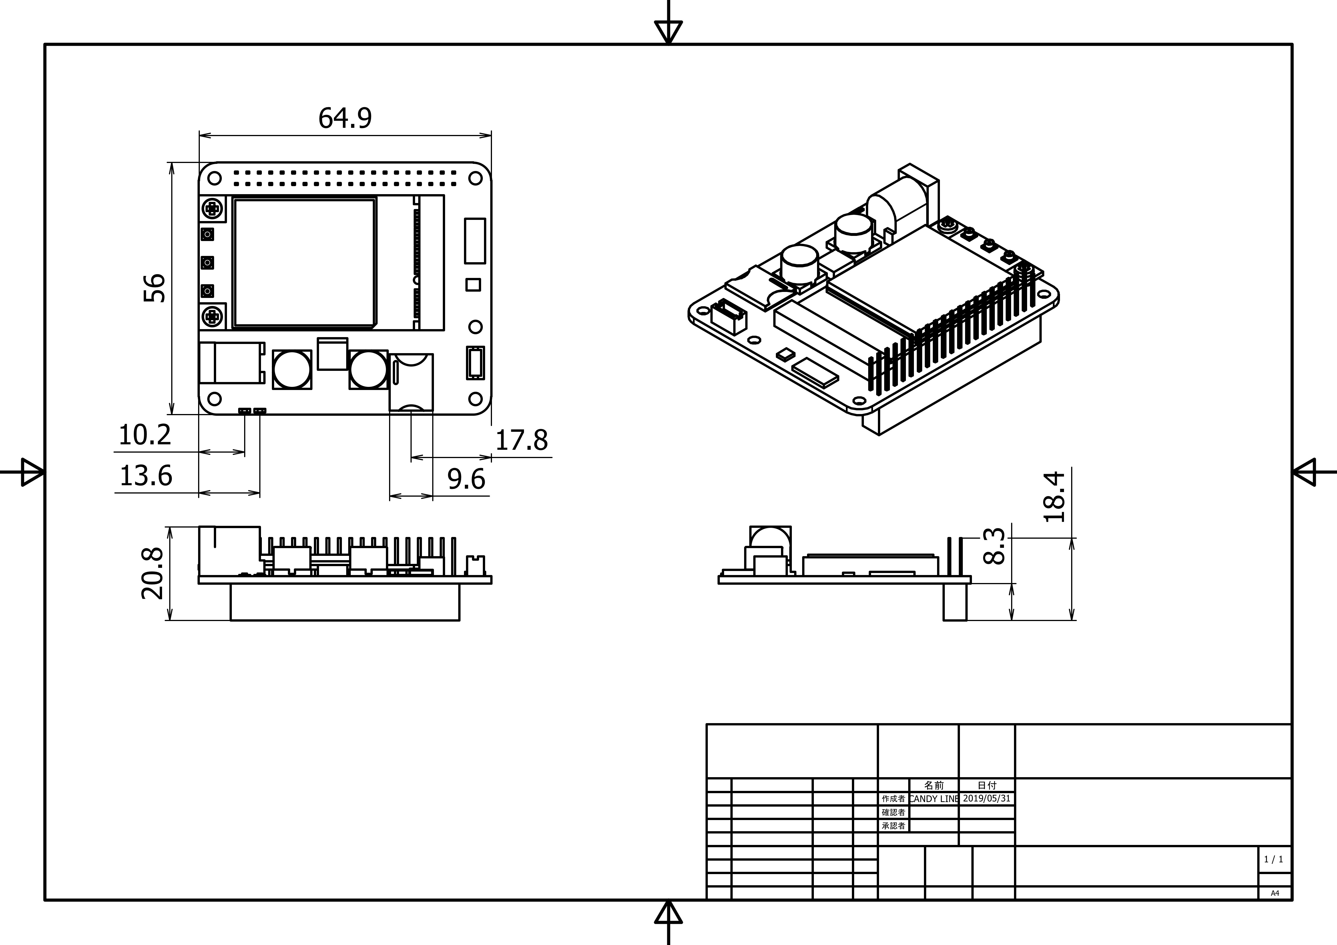
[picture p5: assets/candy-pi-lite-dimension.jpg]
CANDY Pi Lite/CANDY Pi Lite+ 立体


## USB拡張ボード取り付け時のCANDY Pi Lite/CANDY Pi Lite+本体寸法

- [CAD図面（DXF形式）ダウンロード](/assets/candy-pi-lite-dimension_usbboard.dxf) ※3DCG用のモデルではありません
- [3Dモデル（STEP形式）ダウンロード](/assets/candy-pi-lite-dimension_usbboard.stp) ※各種ブラウザービューワー([Autodesk® Viewer](https://viewer.autodesk.com/), [STP Viewer](https://3d-viewers.com/step-viewer.html) など)でも3Dモデルを閲覧できます

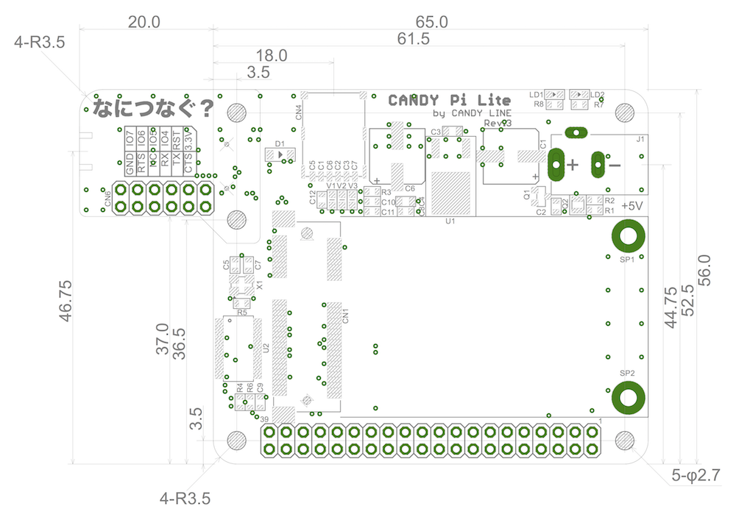
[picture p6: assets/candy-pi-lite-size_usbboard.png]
CANDY Pi Lite/CANDY Pi Lite+ with USB board 平面


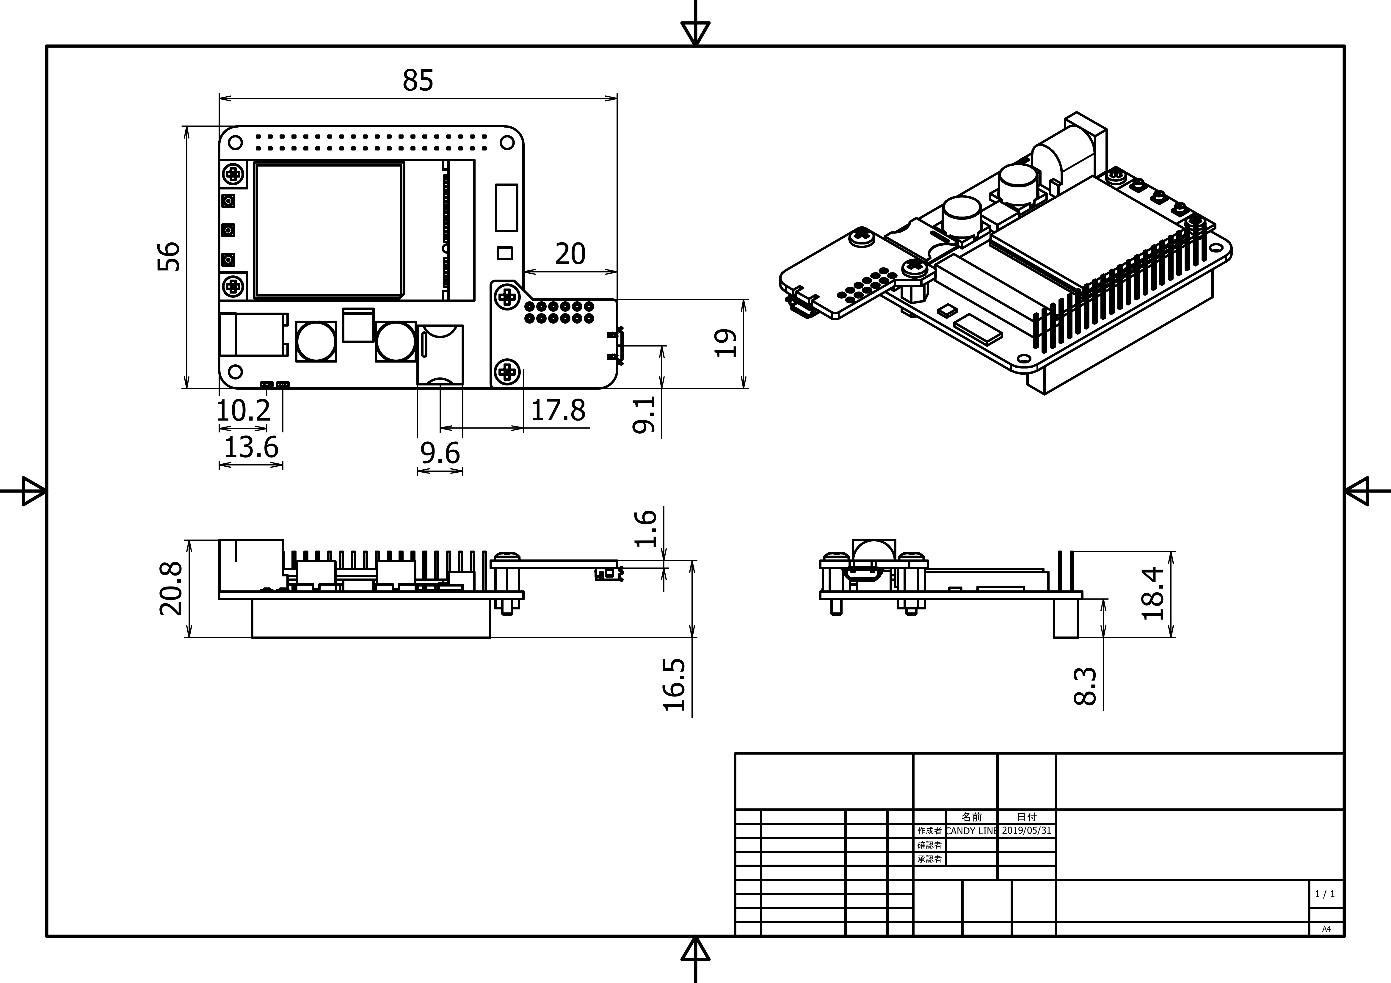
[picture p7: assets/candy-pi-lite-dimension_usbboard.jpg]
CANDY Pi Lite/CANDY Pi Lite+ with USB board 立体


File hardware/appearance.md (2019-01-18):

<!-- toc -->

# 本体基板外観

** 👉　製品の外観や仕様は、製品改善により予告なく変更されることがあります。 **

## CANDY Pi Lite 3Gモデル

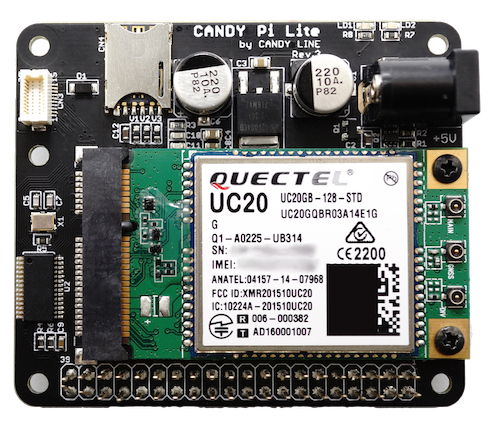
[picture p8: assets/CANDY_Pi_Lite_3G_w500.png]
CANDY Pi Lite 3G


## CANDY Pi Lite LTE(4G)モデル

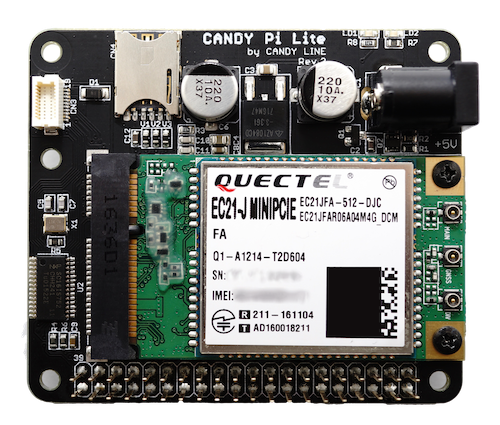
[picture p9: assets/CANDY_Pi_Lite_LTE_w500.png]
CANDY Pi Lite LTE


## CANDY Pi Lite +D（NTTドコモ向け）モデル

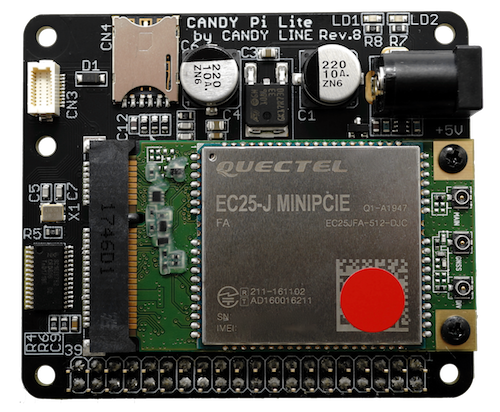
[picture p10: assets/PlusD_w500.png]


## CANDY Pi Lite +K（au/KDDI向け）モデル

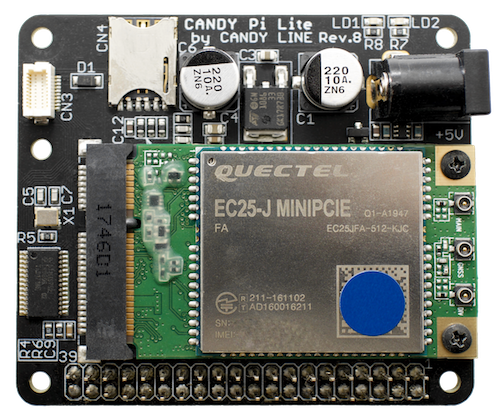
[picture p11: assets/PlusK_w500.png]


## CANDY Pi Lite +S（ソフトバンク向け）モデル

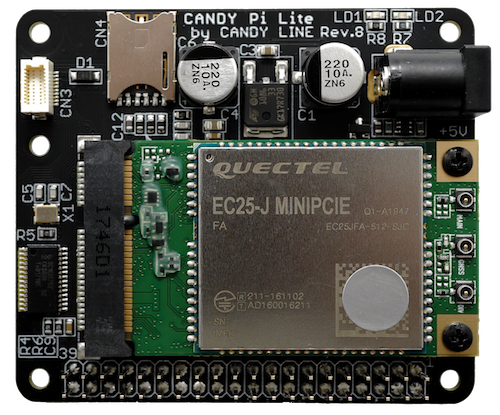
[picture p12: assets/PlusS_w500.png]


# 本体基板の見分け方

## CANDY Pi Lite 3Gモデル

通信モジュール機種名に「UC20」の文字列があります。この場合は、3Gモデルとなります。

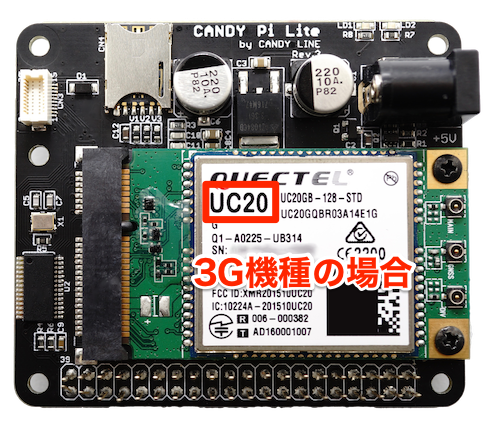
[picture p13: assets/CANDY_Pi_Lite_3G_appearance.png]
CANDY Pi Lite 3G


## CANDY Pi Lite LTE(4G)モデル

通信モジュール機種名に「EC21-J MINIPCIE」の文字列があります。この場合は、LTEモデルとなります。写真では「EC21-J」とありますが、「-J」の部分は日本国内の電波帯域で利用可能であることを示しています。

また、出荷時期によっては「EC21-J」と表示されている場合があります。この場合もLTEモデルとなります。

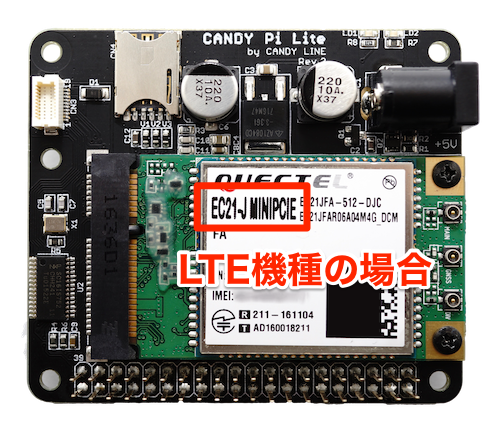
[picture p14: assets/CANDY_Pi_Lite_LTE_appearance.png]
CANDY Pi Lite LTE


## CANDY Pi Lite +D（NTTドコモ向け）モデル

通信モジュール機種名に「EC25」の文字列があり、さらに右下に赤い円形のステッカーが貼り付けられています。

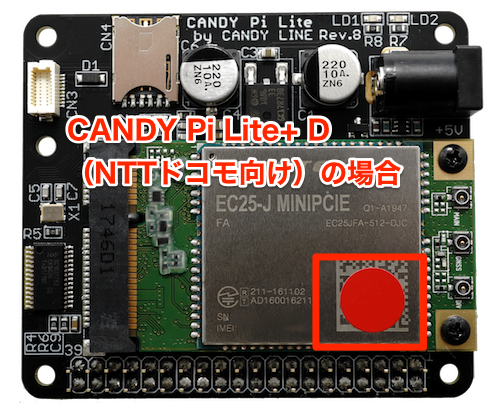
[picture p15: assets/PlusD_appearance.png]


## CANDY Pi Lite +K（au/KDDI向け）モデル

通信モジュール機種名に「EC25」の文字列があり、さらに右下に青い円形のステッカーが貼り付けられています。

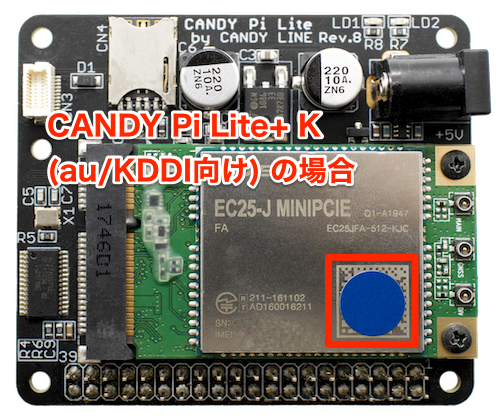
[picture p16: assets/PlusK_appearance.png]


## CANDY Pi Lite +S（ソフトバンク向け）モデル

通信モジュール機種名に「EC25」の文字列があり、さらに右下に銀色・円形のステッカーが貼り付けられています。

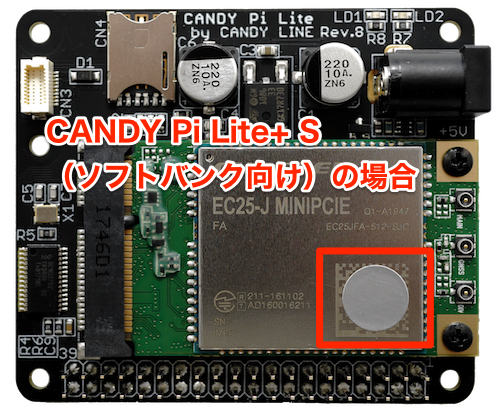
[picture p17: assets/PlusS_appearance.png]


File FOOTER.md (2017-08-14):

© CANDY LINE INC. | [CC-BY-NC-SA 4.0](https://creativecommons.org/licenses/by-nc-sa/4.0/) | 最終更新日:{{ file.mtime }}

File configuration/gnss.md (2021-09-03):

## GNSS/GPSの使用

**👉[`candy-pi-lite-service v5.0.0`](https://forums.candy-line.io/t/v5-0-0)以降で対応しています**

CANDY Pi Lite 3GとCANDY Pi Lite+では、専用のアンテナを取り付けることによりGPSの機能を使用することができます。コマンドラインまたは[CANDY RED](https://github.com/CANDY-LINE/candy-red)を使用して、GPSの機能を利用することが可能です。GPSの情報は、JSON形式での取得または、NMEAフォーマットのデータの連続出力を得ることが可能です。

ただし、初期状態では、GNSS/GPSが起動していませんので、[コマンドライン](/cli/gnss.md)で明示的に起動するか、後述のGNSS自動起動を設定しておく必要があります。

[CANDY RED](https://github.com/CANDY-LINE/candy-red)を使用すると、専用のソフトウェアを用意せずにGPSの機能を使ったアプリケーションを作成することができます。詳細については、フォーラムにて投稿予定です。

GNSS/GPS機能をコマンドラインで起動、停止、状態確認、位置取得を行う場合は、[こちらのページ](/cli/gnss.md)をご覧ください。

## 対応しているGNSS種類

GPSのほか、QZSS（みちびき）を利用可能です。モジュールの仕様により、QZSS（みちびき）を有効にするとGalileo、GLONASS、北斗も有効になります。
ただし、GPSとQZSS（みちびき）以外の利用については、CANDY LINEでは未確認であり、サポートもしておりません。

**ご注意**
- QZSS（みちびき）は、CANDY Pi Lite+シリーズのみ利用可能です。

## NMEAによるGPSの位置取得

USB接続時には、NMEAセンテンス専用のシリアルポート`/dev/QWS.UC20.NMEA`、または`/dev/QWS.EC25.NMEA`を利用することができます。ボーレートは、9600bpsとなります。それぞれ、次の機種に対応します。

- `/dev/QWS.UC20.NMEA` ... CANDY Pi Lite 3G
- `/dev/QWS.EC25.NMEA` ... CANDY Pi Lite+

**👉 CANDY Pi Lite LTEモデルでは対応していません。**

本機能は、NMEA（NMEA 0183）について予備知識のある方向けの機能となります。NMEAの詳細については本書では扱いませんので、ご利用者の方にて予めお調べの上お使いください。`cgps`コマンドを使うとターミナル上でNMEAの情報を簡易に見ることが可能です。詳しくは、[こちらの投稿](https://forums.candy-line.io/t/gpsd/172/5)を参照してください。

## インストール時にGNSS自動起動を設定するには

`candy-pi-lite-service`のインストール時に以下のように`GNSS_ON_STARTUP=1`を設定することにより、初期状態では、GNSSを起動しないようになっています（`0`が指定される）。

```bash
$ curl -sL https://git.io/v7bXx | sudo GNSS_ON_STARTUP=1 BOOT_APN=<apn名> bash
```

## インストールした後にGNSS自動起動設定を変更する方法

また、**インストールした後** で挙動を変更したい場合は、以下のように環境変数ファイルを開きます。

```bash
$ sudo nano /opt/candy-line/candy-pi-lite/environment
```

すると以下のような箇所がありますので、
```
# Set 1 for starting GNSS session on start-up
GNSS_ON_STARTUP=0
```

`0`の代わりに`1`を指定します。
```
GNSS_ON_STARTUP=1
```
ファイルを保存したら、[candy-pi-lite サービスを再起動](/service/restart.md)するかシステムを再起動してください。

## QZSS（みちびき）を自動起動時に有効にする方法
**👉[`candy-pi-lite-service v10.4.0`](https://forums.candy-line.io/t/candy-pi-lite-v10-4-0)以降で対応しています**

QZSS（みちびき）を有効にしたいときは、`1`の代わりに`2`または`3`を指定します。
```
GNSS_ON_STARTUP=2
```
値の意味は以下の通りです。どちらの値もQZSS（みちびき）を有効にできますが、同時に有効となるGNSSサービスの種類が異なります。これらの動作の違いはCANDY LINEの仕様ではなく、モジュール側の挙動によるものです。QZSS（みちびき）だけをご利用になる場合はどちらの値をご利用いただいても問題ないでしょう。

- `2`・・・QZSS（みちびき）を有効にします。同時に、GLONASSと北斗も有効になります（これら2つは無効にできません）
- `3`・・・QZSS（みちびき）を有効にします。同時に、Galileo、GLONASS、北斗も有効になります（これら3つは無効にできません）

ファイルを保存したら、[candy-pi-lite サービスを再起動](/service/restart.md)するかシステムを再起動してください。

**ご注意**
- QZSS（みちびき）は、CANDY Pi Lite+シリーズのみ利用可能です。

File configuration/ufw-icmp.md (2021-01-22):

# ufwを利用してグローバルIP経由のPingを拒否する方法

**👉CANDY Pi Lite LTE-Mでは機能しません**

OCN mobile oneなど一部のSIM回線をご利用の場合、グローバルIPが割当たる場合があります。また、固定IPを利用できるSIM回線をご利用の場合も同様です。その場合には、`ping`コマンドを拒否したいケースがあるかもしれません。

以下の手順に従って設定を行うと、`ping`コマンドの要求をファイヤーウォールで拒否することができます。

## IPv4

```
$ sudo vi /etc/ufw/before.rules
(下記の変更を適用)
$ sudo ufw disable; sudo ufw --force enable
```

### before.rulesファイルの変更内容

```
変更前（以下の箇所を探してください）:
-A ufw-before-input -p icmp --icmp-type echo-request -j ACCEPT

変更後（DROPの行を追加します）:
-A ufw-before-input -p icmp -i ppp0 --icmp-type echo-request -j DROP
-A ufw-before-input -p icmp --icmp-type echo-request -j ACCEPT
```

## IPv6

```
$ sudo vi /etc/ufw/before6.rules
(下記の変更を適用)
$ sudo ufw disable; sudo ufw --force enable
```

### before6.rulesファイルの変更内容

```
変更前（以下の箇所を探してください）:
-A ufw6-before-input -p icmpv6 --icmpv6-type echo-request -j ACCEPT

変更後（DROPの行を追加します）:
-A ufw6-before-input -p icmpv6 -i ppp0 --icmpv6-type echo-request -j DROP
-A ufw6-before-input -p icmpv6 --icmpv6-type echo-request -j ACCEPT
```

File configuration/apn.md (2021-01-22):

<!-- toc -->

# APN設定

CANDY Pi Liteの携帯電話ネットワークへの接続先(APN)は、インストール時に指定することができます。この宛先は、インストール後に変更することが可能です。異なるMVNOのSIMカードを変更したときには、APNの変更も行うようにしましょう。

[`candy-pi-lite-service v1.7.0`](https://forums.candy-line.io/t/v1-7-0/63)からAPNの指定方法が簡単になりました。以前のバージョンをご利用の場合は、本章の後半をご覧ください。

## APNの指定

**👉[`candy-pi-lite-service v6.2.0`](https://forums.candy-line.io/t/candy-pi-lite-v6-2-0/238)以降で対応しています**

APNを指定するには、パソコンなどでマイクロSDカードの`/boot`ディレクトリーに`apn`または`apn.txt`という名前のファイルを作成します。ファイルの中身は、APNの名称または設定名を指定します。初期状態では、[プリセットされたAPNの一覧](apn-list.md)に記載された名称を利用可能です。

例えば、IIJモバイル／タイプIのSIMをご利用の場合は、メモ帳やテキストエディターなどで`iijmobile.biz-ipv6`とだけ入力し保存します。

> ### <👉補足説明>
>
> 上記の例では、`apn`（または`apn.txt`）ファイルの値に`iijmobile.biz-ipv6`を設定すると記載しています。本来IIJモバイル／タイプIの標準的なAPN名は`iijmobile.biz`ですが、同じAPNでも異なる設定で接続できるようにするため、別名を設定名としてつけることが可能です。このため、`iijmobile.biz-ipv6`を`/boot/apn`（または`/boot/apn.txt`）ファイルに指定しても、その値がAPN名となることはありません。

その後、そのマイクロSDを利用してRaspberryPiを起動してください。すると自動的にそのAPNが選択されるようになります。また、`/boot`に保存したファイルはAPNの設定が成功すると削除されます。

ただし、APNに上記以外のAPNを指定した時は、エラーとなり`/boot`に保存した`apn`（または`apn.txt`）ファイルはそのまま削除されずに残ったままとなります。

## APNの簡易追加

**👉[`candy-pi-lite-service v6.2.0`](https://forums.candy-line.io/t/candy-pi-lite-v6-2-0/238)以降で対応しています**

APNを追加する場合も、`/boot`ディレクトリーに`apn`（または`apn.txt`）という名前のファイルを作成して追加することができるようになりました。この場合は、以下のようにAPNの他、ユーザーIDとパスワードも指定しなければなりません。また、JSON形式ですので書式が間違っていると正しく追加されませんのでご注意ください。エラーとなった場合は、先程と同様に、`/boot/apn`（または`/boot/apn.txt`）のファイルは削除されずに残されています。

また、エラーメッセージについては、`/var/log/syslog`にも表示されますので、うまく設定されない場合はこのログをご確認ください。

APNを追加したい場合の`apn`ファイルの中身は以下のような書式になります。
```
{
  "apn": "APN",
  "user": "ユーザーID",
  "password": "パスワード"
}
```

上記のうち、`APN`、`ユーザーID`、`パスワード`の部分を書き換えてください。ダブルクォーテーション「"」はそのまま残しておいてください。

### 音声・SMS回線向けの設定

音声・SMS回線を同時に契約されたSIMをお使いの場合は、以下の設定もお試しいただけます。

```
{
  "apn": "APN",
  "user": "ユーザーID",
  "password": "パスワード",
  "cs": true
}
```

`"cs": true`を指定すると、音声回線網への登録が確認できた後で通信を開始します。この指定をすると接続までの時間が短くなる場合がありますが、お試しの上効果がなければ外しても問題ありません。なお、データ通信回線をお使いの場合、この指定をすると正しく動作しませんのでご注意ください。

### IPv4/IPv6デュアルスタックまたはIPv6向けの設定

IPv4/IPv6デュアルスタックネットワークやIPv6ネットワークに対応したAPNがある場合は、以下の設定を指定することが可能です。

```
{
  "apn": "APN",
  "user": "ユーザーID",
  "password": "パスワード",
  "pdp": "PDP種別"
}
```

上記の`PDP種別`の欄には、以下のいずれかの値を指定します。

- `ipv4v6` ... IPv4/IPv6デュアルスタックネットワークへ接続する場合
- `ipv6` ... IPv6ネットワークへ接続する場合

また、IPv6ネットワークにおいては、DHCPv6によるDNSv6自動設定が有効に働かない場合があります。その場合は、以下の形で、IPv6のDNSアドレスを指定してください。

```
{
  "apn": "APN",
  "user": "ユーザーID",
  "password": "パスワード",
  "pdp": "ipv6",
  "ipv6dns1": "2001:4860:4860::8888",
  "ipv6dns2": "2001:4860:4860::8844"
}
```

上記の例では、GoogleのDNSを指定しています。

### MCC/MNCの指定

**👉 この設定は、上級者向けです。この内容があてはまるか不明な場合は、この設定を行なってはいけません。**

通常、CANDY Pi Liteは、ご利用のSIMカードに合わせて自動的に使用するモバイルネットワークを検出します。しかし、SORACOMグローバルSIMなどNTTドコモを使用したローミングSIMにおいて、自動検出に5分前後の時間がかかる事象を確認しました。このため、あらかじめ使用するネットワークオペレーターがわかっている場合は、そのオペレーターのMCC（モバイルネットワークの国・地域コード）とMNC（電気通信事業者識別番号）をAPN設定に指定できるようにしています。これにより、モバイルネットワークへ速やかに接続ができるようになります。

以下は、NTTドコモのネットワークを使用することが明らかな場合の設定です。`ops`は、オペレーター選択を有効にするかどうかを、`true`（選択を有効にする）または`false`（選択を有効にしない）で指定します。

```
{
  "apn": "APN",
  "user": "ユーザーID",
  "password": "パスワード",
  "ops": true,
  "mcc": "440",
  "mnc": "10"
}
```

`"ops": true`だけを指定して、`"mcc"`と`"mnc"`を省略すると、既存オペレーターネットワークの選択を解除して、自動選択しなおすことを意味します。

### 接続先ネットワーク種類（3G/4G LTE）の限定

**👉 この設定は、上級者向けです。この内容があてはまるか不明な場合は、この設定を行なってはいけません。**

CANDY Pi Lite+をご利用の場合、回線契約やご利用中のキャリアが3G/4G LTE共に利用できる時は、CANDY Pi Liteは自動的に使用する接続先ネットワーク種類を決定します。
ご利用者の方にて任意の接続先ネットワーク種類を使用したい時は、以下のようにAPN設定にて`"nw"`を指定します。

```
{
  "apn": "APN",
  "user": "ユーザーID",
  "password": "パスワード",
  "nw": "ネットワーク種類"
}
```

指定可能なネットワーク種類は以下の通りです。

- `auto` ... 自動選択（省略時の初期設定値）
- `3g` ... 3Gネットワーク限定
- `lte` ... 4G LTEネットワーク限定

## プリセットAPNの追加・変更

**👉[`candy-pi-lite-service v1.7.0`](https://forums.candy-line.io/t/v1-7-0/63)以降ではより簡単な方法もご利用いただけます**

初期状態で指定できる4つのAPNに加え、ご利用の方々が任意のAPNを追加することができます。初期状態以外のMVNOや閉域網に接続する時や、既存の接続先の設定を変更するなど、任意のAPNを追加・変更する場合は以下の手順をおこなってください。

1. `/opt/candy-line/candy-pi-lite/apn-list.json` をエディター(`vi`や`nano`など)で開きます
1. 一番最後の行で新しいデータを追加します（下記参照）
1. 中身を保存します

```
{
   "soracom.io":{"user":"sora","password":"sora"}
  ,"lte-d.ocn.ne.jp":{"user":"mobileid@ocn","password":"mobile"}
  ,"3g-d-2.ocn.ne.jp":{"user":"mobileid@ocn","password":"mobile"}
  ,"iijmio.jp":{"user":"mio@iij","password":"iij"}
<<ここに追加します>>
}
```
追加するデータの書式は以下の通りです。

```
,"APN名":{"user":"APNユーザーID","password":"APNパスワード"}
```
最初のカンマはつけておいてください。

なお、追加したAPNの指定も忘れずに行ってください。`apn-list.json`に追加するだけでは、そのAPNを利用できません。

## APNの指定 *（v1.7.0より古い場合）*

**👉[`candy-pi-lite-service v1.7.0`](https://forums.candy-line.io/t/v1-7-0/63)以降では上記に記載した`/boot/apn`ファイルを用いたより簡単な方法をご利用いただけます**

CANDY Pi Liteの携帯電話ネットワークへの接続先(APN)は、`/opt/candy-line/candy-pi-lite/environment`にある以下の箇所に定義されています。

```
# LTE/3G access point name defined in `apn-list.json`
APN=soracom.io
```

**ご注意：最初に`soracom.io`以外のAPNを指定した場合は、上記には指定されたAPNが書かれています。**

このAPNを変更すると、任意のAPNに接続することができます。ただし、初期状態では[プリセットされたAPNの一覧](apn-list.md)の中からのみ指定することができます。

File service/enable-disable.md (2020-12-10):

<!-- toc -->

# candy-pi-lite サービスの有効化・無効化

candy-pi-lite サービスを有効化・無効化するには、ターミナルから以下のコマンドを実行してください。
サービスを有効化すると、OSが起動したときに自動でサービスが起動されます。反対にサービスを無効化すると、OSが起動してもサービスは起動されません。
また、サービスの有効化・無効化を行った場合、サービスが新たに起動されたり、起動中のサービスが停止したりすることはありません。サービスの起動と停止は必要に応じて新たにコマンドを実行してください。

## サービスを有効化する

```bash
$ sudo candy service enable
```

## サービスを無効化する

```bash
$ sudo candy service disable
```

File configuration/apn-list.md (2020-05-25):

<!-- toc -->

# プリセットされたAPNの一覧

初期状態では、以下のキーワードを`/boot/apn`ファイルに指定することができます。APNの指定方法やプリセットAPNの追加・変更方法については、[APN設定](apn.md)をご覧ください。

- `soracom.io` ... [ソラコム](https://soracom.jp)　IPv4ネットワーク(3G/LTE共通、主にSORACOM日本向けAir SIM向け。plan-D、plan-K共通)
- `soracom.io-docomo` ... [ソラコム](https://soracom.jp)　IPv4ネットワーク NTTドコモネットワーク限定(3G/LTE共通、主にSORACOMグローバルAir SIM向け)
- `lte-d.ocn.ne.jp` ... [OCNモバイルONE](https://www.ntt.com/personal/services/mobile/one.html)　IPv4ネットワーク(LTE専用)
- `3g-d-2.ocn.ne.jp` ... [OCNモバイルONE](https://www.ntt.com/personal/services/mobile/one.html)　IPv4ネットワーク(3G専用)
- `iijmobile.biz` ... [IIJモバイル／タイプI](https://www.iij.ad.jp/biz/iijmobile/) **＜フルMVNO＞** IPv4ネットワーク(3G/LTE共通)
- `iijmobile.biz-ipv4v6` ... [IIJモバイル／タイプI](https://www.iij.ad.jp/biz/iijmobile/) **＜フルMVNO＞** IPv4/IPv6デュアルスタックネットワーク(3G/LTE共通)
- `iijmobile.biz-ipv6` ... [IIJモバイル／タイプI](https://www.iij.ad.jp/biz/iijmobile/) **＜フルMVNO＞** IPv6ネットワーク(3G/LTE共通)
- `iijmio.jp` ... [IIJmio／タイプD・タイプA](https://www.iijmio.jp) IPv4ネットワーク(3G/LTE共通)
- `iijmio.jp-ipv4v6` ... [IIJmio／タイプD・タイプA](https://www.iijmio.jp) IPv4/IPv6デュアルスタックネットワーク(3G/LTE共通)
- `iijmio.jp-ipv6` ... [IIJmio／タイプD・タイプA](https://www.iijmio.jp) IPv6ネットワーク(3G/LTE共通)
- `iijmobile.jp` ... [IIJモバイル／タイプD・タイプK](https://www.iij.ad.jp/biz/iijmobile-dk/) IPv4ネットワーク(3G/LTE共通)
- `iijmobile.jp-ipv4v6` ... [IIJモバイル／タイプD・タイプK](https://www.iij.ad.jp/biz/iijmobile-dk/) IPv4/IPv6デュアルスタックネットワーク(3G/LTE共通)
- `iijmobile.jp-ipv6` ... [IIJモバイル／タイプD・タイプK](https://www.iij.ad.jp/biz/iijmobile-dk/) IPv6ネットワーク(3G/LTE共通)
- `sd.iijmobile.jp` ... [IIJモバイル（下り最大150Mbpsの通信速度向け）／タイプD・タイプK](https://www.iij.ad.jp/biz/iijmobile-dk/) IPv4ネットワーク(3G/LTE共通)
- `internet4gd.gdsp` ... [Vodafone Global Enterprise M2M](https://www.vodafone.com/business/iot/japan/global-sim) IPv4ネットワーク(3G/LTE共通)
- `m2m4biz.softbank` ... [Softbank IoT/M2M SIMカード](https://www.softbank.jp/biz/iot/) IPv4ネットワーク(3G/LTE共通)
- `isp.docomoiot.net` ... [docomo IoTスターターSIMカード](https://www.nttdocomo.co.jp/biz/special/iot/) IPv4ネットワーク(3G/LTE共通)
- `ipsim.net` ... [固定IPアドレスSIM イプシム](https://ipsim.net)([Qiita解説記事](https://qiita.com/ipsim_net/items/9cccb64a5afcc03ec0f1))
- `rokemoba` ... [ロケットモバイル](https://rokemoba.com)([TwitterでのCANDY Pi Lite対応済みツイート](https://twitter.com/rokemoba/status/1039000912604278786))
- `au.au-net.ne.jp` ... [au/KDDI LTE NET for DATA](https://www.au.com/mobile/charge/internet-connection/ltenet-for-data/)
- `uqmobile.jp` ... [UQ mobile](https://www.uqwimax.jp/mobile/)
- `sakura-kddi` ... [さくらセキュアモバイルコネクト au/KDDI網向け。網ごとにAPNの指定が必要です。](https://www.sakura.ad.jp/services/sim/)
- `sakura-docomo` ... [さくらセキュアモバイルコネクト NTTドコモ網向け。網ごとにAPNの指定が必要です。](https://www.sakura.ad.jp/services/sim/)
- `sakura-softbank` ... [さくらセキュアモバイルコネクト Softbank網向け。網ごとにAPNの指定が必要です。](https://www.sakura.ad.jp/services/sim/)
- `spmode.ne.jp` ... [NTTドコモ SPモード](https://www.nttdocomo.co.jp/service/spmode/)

**⚠️ご注意）IIJのSIMカードでIPv6をご利用の場合は、「CANDY Pi Lite LTE」をご利用ください。[IIJのエンジニアによる公式blog「てくろぐ」記事内「IPv6が利用可能な条件」](http://techlog.iij.ad.jp/archives/411)に記載の通り、LTEに対応した端末のみ同社のIPv6はサポートされます。このため、「CANDY Pi Lite 3G」はこの条件に当てはまりませんので、当該機種ではIIJのIPv6をご利用いただけません。**

**⚠️ご注意）SORACOM Air SIMのグローバル向けSIMカードを日本国内でご利用の場合は「`soracom.io-docomo`」を推奨します。標準のAPN設定「`soracom.io`」をご利用の場合は、接続までに5分前後の時間がかかる場合があります。**

**⚠️ご注意）ソフトバンクネットワークを使用するSIMカードを利用するには、`CANDY Pi Lite+ S` が必要です。 **

**⚠️ご注意）au/KDDIネットワークを使用するSIMカードを利用するには、`CANDY Pi Lite+ K` が必要です。 **

**⚠️ご注意）docomoネットワークを使用するSIMカードを利用する場合は、`CANDY Pi Lite LTE`、`CANDY Pi Lite 3G`、`CANDY Pi Lite+ D`、あるいは `CANDY Pi Lite+ K` が必要です。 **

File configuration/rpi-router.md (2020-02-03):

# RaspberryPi(Raspbian)でモバイルルーターとして使用する設定

**👉[`candy-pi-lite-service v4.0.0`](https://forums.candy-line.io/t/v4-0-0)以降で対応しています**

CANDY Pi Liteを「Raspbian（ラズビアン）」で動作させるとき、設定を変更するとルーターとして扱うことができるようになります。ここでは、有線LANまたは無線LANから接続したデバイスが、CANDY Pi Liteのモバイルネットワーク接続を利用できるようにするための設定を説明します。

なお、モバイルネットワークに接続していない状態ではアクセスポイントのSSIDは利用できません。その場合でも、モバイルネットワークに再接続すると再びSSIDが利用可能です（**👉[`candy-pi-lite-service v7.0.3`](https://forums.candy-line.io/t/v7-0-3)以降で対応**）。

**👉 CANDY Pi Lite専用のOSイメージ v3.0.0以降では、すでにソフトウェアがインストールされていますが、初期状態では無効になっています**

なお、こちらの手順は、raspberrypi.orgの[Wi-Fiのアクセスポイントを設定するための手順](https://www.raspberrypi.org/documentation/configuration/wireless/access-point.md)をベースに作成しています。しかし、その手順とは異なり、`iptables`を直接利用しません。代わりに`ufw`を設定します。`ufw`の設定の詳細は、[Gist kimus/9315140](https://gist.github.com/kimus/9315140)の方法をベースに記載しています。

以下の手順を途中で中断すると、有線LANや無線LANが意図通りに接続できなくなる場合があります。その場合は、シリアルコンソールで設定を変更するか、OSイメージを書き直して最初からやり直してください。

## 有線LAN・無線LAN共通の手続き

### 追加ソフトウェアのインストール

**👉 専用イメージ利用時はこのインストール作業は不要です**

ラズパイをルーターとして動作させるために、DHCPサーバーの機能を追加します。

なお、CANDY Pi Liteを接続してインターネットに接続している場合は必ず下記コマンドを停止してください。

```
$ sudo systemctl stop candy-pi-lite
$ sudo apt-get update
$ sudo apt-get install dnsmasq
```

`dnsmasq`の設定をしていないため、一旦サービスを停止します。

```
$ sudo systemctl stop dnsmasq
```

### `ufw`の設定変更

`ufw`の設定を変更してルーティングを行うようにします。

```
$ sudo nano /etc/default/ufw
```

ここで、`DEFAULT_FORWARD_POLICY`の値を以下のように変更します。

```
DEFAULT_FORWARD_POLICY="ACCEPT"
```

続いて、`ufw`のルールファイルを変更します。

```
$ sudo nano /etc/ufw/before.rules
```

ここで、`*filter`と書かれた先頭の方にある設定の **前** に、以下の行を追加します。

```
# NAT table rules
*nat
:POSTROUTING ACCEPT [0:0]

# Forward traffic through ppp0
-A POSTROUTING -o ppp0 -j MASQUERADE

# don't delete the 'COMMIT' line or these nat table rules won't
# be processed
COMMIT
```

最後の`COMMIT`まで追加してください。

### `sysctl.conf`の設定変更

ipv4/ipv6のパケットフォワードを有効にするために、`sysctl.conf`を変更します。

```
$ sudo nano /etc/sysctl.conf
```

初期状態では通常コメントアウトされているので、以下のように`net.ipv4.ip_forward=1`の行の先頭の`#`を外してください。

```
# Uncomment the next line to enable packet forwarding for IPv4
net.ipv4.ip_forward=1

# Uncomment the next line to enable packet forwarding for IPv6
#  Enabling this option disables Stateless Address Autoconfiguration
#  based on Router Advertisements for this host
#net.ipv6.conf.all.forwarding=1
```

これ以降は、有線LAN経由でラズパイに接続する場合と、無線LAN経由でラズパイに接続する場合とで設定方法が異なりますので、目的に応じて手順を進めてください。

## 有線LANを経由した接続の場合

### 固定IPの設定

こちらは、有線LAN経由でラズパイに搭載されたCANDY Pi Liteの通信を使用する方法の設定手順です。

まずは固定IPを`eth0`に割り当てます。

```
$ sudo nano /boot/boot-ip.json
```

として、以下の内容を書き込みます。

```
{
  "ip_address":"192.168.5.1/24",
  "interface":"eth0"
}
```

### DHCPサーバーの設定

続いて、DHCPの設定を行います。

既存の`dnsmasq`の設定をバックアップして、新しい設定を保存します。

```
$ sudo mv /etc/dnsmasq.conf /etc/dnsmasq.conf.orig  
$ sudo nano /etc/dnsmasq.conf
```

新しい設定には以下の内容を書き込みます。
```
interface=eth0
  dhcp-range=192.168.5.2,192.168.5.20,255.255.255.0,24h
```

### 再起動

再起動後に`dnsmasq`サービスが起動するように有効にします。

```
$ sudo systemctl enable dnsmasq
```

これで準備は整いました。ラズパイを再起動してください。CANDY Pi Liteがモバイルネットワークに接続したら、Ethernetケーブルで接続したコンピューターからインターネットへアクセスを試みてください。

## 無線LANを経由した接続の場合

### 追加ソフトウェアのインストール

**👉 専用イメージ利用時はこのインストール作業は不要です**

無線LANのアクセスポイントを作成するために`hostapd`をインストールします。

```
$ sudo apt-get install hostapd
```

`hostapd`の設定をしていないため、一旦サービスを停止します。

```
$ sudo systemctl stop hostapd
```

### 固定IPの設定

次に固定IPを`wlan0`に割り当てます。

```
$ sudo nano /boot/boot-ip.json
```

として、以下の内容を書き込みます。

```
{
  "ip_address":"192.168.4.1/24",
  "interface":"wlan0"
}
```

### DHCPサーバーの設定

続いて、DHCPの設定を行います。

既存の`dnsmasq`の設定をバックアップして、新しい設定を保存します。

```
$ sudo mv /etc/dnsmasq.conf /etc/dnsmasq.conf.orig  
$ sudo nano /etc/dnsmasq.conf
```

新しい設定には以下の内容を書き込みます。
```
interface=wlan0
  dhcp-range=192.168.4.2,192.168.4.20,255.255.255.0,24h
```

### Wi-Fiアクセスポイントの設定

新しいWi-Fiアクセスポイントの作成に必要な情報をファイルに書き込みます。

```
$ sudo nano /etc/hostapd/hostapd.conf
```

以下の設定は、WPA2のものです。SSIDやパスフレーズなどを必要に応じて変更してください。

```
interface=wlan0
driver=nl80211
ssid=SSID名をここに書く
hw_mode=g
channel=7
ieee80211n=1
wmm_enabled=1
macaddr_acl=0
auth_algs=1
ignore_broadcast_ssid=0
wpa=2
wpa_passphrase=SSIDのパスワードをここに書く
wpa_key_mgmt=WPA-PSK
wpa_pairwise=TKIP
rsn_pairwise=CCMP
```

次にこのファイルを初期設定とするように変更します。

```
$ sudo nano /etc/default/hostapd
```

初期状態では、次のように設定されているところがあります。

```
#DAEMON_CONF=""
```

これを以下のように、`#`を取り除き、`""`の中にパスを追記します。このパスはそのまま変更せずにコピー＆ペースとしてご利用ください。

```
DAEMON_CONF="/etc/hostapd/hostapd.conf"
```

### 再起動

再起動後に`dnsmasq`サービスと`hostapd`サービスが起動するように有効にします。

```
$ sudo systemctl enable dnsmasq
$ sudo systemctl enable hostapd
```

これで準備は整いました。ラズパイを再起動してください。指定したSSIDが見えるようになったらアクセスポイントにつないでみましょう。アクセスポイントで接続できたら、接続したコンピューターからインターネットへアクセスを試みてください。

なお、Wi-Fiで接続した時にはラズパイのIPアドレスは、`192.168.4.1`となります。

### Wi-Fi設定時のコマンドの履歴例

OSイメージを使用した場合は、次のようなコマンド実行履歴となります。

```
$ sudo systemctl stop candy-pi-lite
$ sudo nano /etc/default/ufw
$ sudo nano /etc/ufw/before.rules
$ sudo nano /etc/sysctl.conf
$ sudo nano /boot/boot-ip.json
$ sudo mv /etc/dnsmasq.conf /etc/dnsmasq.conf.orig
$ sudo nano /etc/dnsmasq.conf
$ sudo nano /etc/hostapd/hostapd.conf
$ sudo nano /etc/default/hostapd
$ sudo systemctl enable dnsmasq
$ sudo systemctl enable hostapd
$ sudo reboot
```

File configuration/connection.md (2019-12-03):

# モバイルネットワークへの接続設定

ここでは、OS起動時のモバイルネットワークへの接続を行うかどうかの設定について説明します。
モバイルネットワークへの接続停止や再開は、[こちらのコマンドライン](/cli/connection.md)にて実施可能です。

## 起動時の接続設定

** 👉[`candy-pi-lite-service v5.0.0`](https://forums.candy-line.io/t/v5-0-0)以降で対応しています **

通常、CANDY Pi Lite/CANDY Pi Lite+が起動した時には、常にモバイルネットワークへ接続します。この動作を初期状態で接続させないように指定することができます。

## インストール時の接続設定

`candy-pi-lite-service`のインストール時に以下のように`CONNECT_ON_STARTUP=0`を設定することにより、初期状態で接続させないようにすることができます。標準では接続するようになっています（`1`が指定される）。

```bash
$ curl -sL https://git.io/v7bXx | sudo CONNECT_ON_STARTUP=0 BOOT_APN=<apn名> bash
```

## インストールした後に変更する方法

また、**インストールした後** で挙動を変更したい場合は、以下のように環境変数ファイルを開きます。

```bash
$ sudo nano /opt/candy-line/candy-pi-lite/environment
```

すると以下のような箇所がありますので、
```
# Set 1 for establishing a connection on start-up
CONNECT_ON_STARTUP=1
```

`1`の代わりに`0`を指定します。
```
CONNECT_ON_STARTUP=0
```
ファイルを保存したら、[candy-pi-lite サービスを再起動](/service/restart.md)するかシステムを再起動してください。

## 初期状態で接続を行わない場合の注意

初期状態で接続を行わないようにした場合、接続状態は「サスペンド」状態として扱われます。接続を行うときは、「[モバイルネットワーク接続の制御](/cli/connection.rd)」の「モバイルネットワーク接続を再開する場合」に記載の`candy connection resume`コマンドを実施してください。

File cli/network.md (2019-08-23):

<!-- toc -->

# ネットワーク状態の表示

現在のネットワークに関する情報を表示することができます。

## 情報表示のコマンド

** 👉[`candy-pi-lite-service v6.3.0`](https://forums.candy-line.io/t/candy-pi-lite-v6-3-0)以降で対応しています **

ネットワークやその状態に関する情報を表示するには、以下のコマンドを実行してください。

```bash
$ sudo candy network show
```

UART接続（USB接続なし）で通信中の場合は、以下のように`--suspend --resume`をつけてください。これらのオプションをつけ忘れると`Modem is not ready`と表示されたり、結果が表示された後で再接続が行われないことがあります。

```bash
$ sudo candy network show --suspend --resume
```

実行すると以下のような結果が表示されます（3G版をお使いの場合は、`eps`の値は`N/A`となります）。

```bash
{
  "network": "N/A",
  "access": "FDD LTE",
  "band": "LTE BAND 1",
  "registration": {
    "cs": "Unregistered",
    "ps": "Registered",
    "eps": "Registered"
  },
  "operator": "NTT DOCOMO NTT DOCOMO",
  "rssi": "-79",
  "rssiDesc": ""
}
```

### 結果の説明

- `network` ... 常に`N/A`を返します。接続状態を知るには、[`connection status`](connection.md)コマンドを利用してください
- `access` ... 無線アクセス技術の種類を示します。`FDD LTE`や`WCDMA`といった値が返ります
- `band` ... 接続している周波数バンドが表示されます。`LTE BAND 1`や`WCDMA 800`といった値が返ります。LTEの場合はLTE BAND 43までの番号が表示されます
- `registration` ... 無線設備への登録状態に関する情報です。`cs`はSMS/音声通信への接続状態を示し、`ps`はデータ通信への接続状態を、また`eps`はLTEのデータ通信への接続状態をそれぞれ示します
- `operator` ... 接続している携帯電話ネトワークオペレーター（通信キャリア）の識別名です
- `rssi` ... 電波強度を表します。単位は、dBmです
- `rssiDesc` ... 電波強度が`rssi`の値より小さいか、より大きいか、電波が検出できない場合にその旨の説明が追加されます。`OR_LESS` は、`rssi`の値未満であることを示します。`OR_MORE`、`rssi`の値より大きいことを示します

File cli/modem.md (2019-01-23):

<!-- toc -->

# 通信モジュール（モデム）情報の表示

通信モジュールに関する情報を表示することができます。また、EC21をお使いの場合は、パケットカウンターの値を表示することができます。

## 情報表示のコマンド

** 👉[`candy-pi-lite-service v6.3.0`](https://forums.candy-line.io/t/candy-pi-lite-v6-3-0)以降で対応しています **

通信モジュールの情報を表示するには、以下のコマンドを実行してください。

```bash
$ sudo candy modem show
```

UART接続（USB接続なし）で通信中の場合は、以下のように`--suspend --resume`をつけてください。これらのオプションをつけ忘れると`Modem is not ready`と表示されたり、結果が表示された後で再接続が行われないことがあります。

```bash
$ sudo candy modem show --suspend --resume
```

実行すると以下のような結果が表示されます。

```bash
{
  "counter": {
    "rx": "0",
    "tx": "0"
  },
  "datetime": "17/08/19,04:02:57",
  "imei": "000000000000000",
  "timezone": 9.0,
  "model": "UC20",
  "revision": "UC20GQBR03A14E1G",
  "manufacturer": "Quectel"
}
```

### 結果の説明

- `counter` ... パケットカウンターの値です。単位はバイトです。UC20では常に0となります
- `datetime` ... 通信モジュール内の時刻です
- `timezone` ... 通信モジュール内のタイムゾーンです
- `model` ... 通信モジュールの機種名です
- `revision` ... 通信モジュールファームウェアのバージョンです
- `manufacturer` ... 通信モジュールのメーカー名です

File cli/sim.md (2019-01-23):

<!-- toc -->

# SIMカード認識状態の表示

現在検出されているSIMカードの状態やその情報を表示することができます。

## 情報表示のコマンド

** 👉[`candy-pi-lite-service v6.3.0`](https://forums.candy-line.io/t/candy-pi-lite-v6-3-0)以降で対応しています **

SIMカードの状態やその情報を表示するには、以下のコマンドを実行してください。

```bash
$ sudo candy sim show
```

UART接続（USB接続なし）で通信中の場合は、以下のように`--suspend --resume`をつけてください。これらのオプションをつけ忘れると`Modem is not ready`と表示されたり、結果が表示された後で再接続が行われないことがあります。

```bash
$ sudo candy sim show --suspend --resume
```

実行すると以下のような結果が表示されます。

```bash
{
  "msisdn": "000111112222",
  "state": "SIM_STATE_READY",
  "imsi": "440100000000000"
}
```

**ご注意：ソラコムグローバルSIMなど一部のSIMカードには、電話番号(`msisdn`)がSIMカードの書かれていないことがあります。その場合は、`msisdn`には電話番号が表示されません。**

### 結果の説明

- `msisdn` ... 電話番号(MSISDN)です
- `state` ... SIMカードの認識状態を表します。`SIM_STATE_READY`であれば認識されています
- `imsi` ... SIMカードに関連づけられているIMSI番号です

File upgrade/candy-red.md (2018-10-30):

<!-- toc -->

# CADNY REDのバージョンアップ

CANDY REDのバージョンアップは、[CANDY REDのインストール](/setup/candy-red.md)と似たような手順で行います。

バージョンアップ後にも、フローファイルはそのまま利用できますが、念のためフローファイルをバックアップしておくことをお勧めします。

### パッケージのアップデート

まず最初に、candy-pi-lite サービスを停止し、LANケーブルまたはWiFiでインターネットに接続します。これは、ダウンロードにかかる通信を携帯電話ネットワークではなく有線・無線LANにて行うようにするためです。

はじめに、以下のコマンドを実行してcandy-pi-lite サービスを停止します。

```bash
$ sudo systemctl stop candy-pi-lite
```

続いて、ネットワークの確認を行います。ラズパイにコマンドラインからアクセスして、以下のコマンドを実行します。

```bash
$ curl --head https://registry.npmjs.org
```

以下のように結果が返って来るようであれば、正しくインターネットに接続できています。

```
HTTP/1.1 200 OK
server: CouchDB/1.5.0 (Erlang OTP/R16B03)
Content-Type: application/json
Cache-Control: max-age=300
Content-Length: 262
Accept-Ranges: bytes
Date: Fri, 16 Sep 2016 05:19:25 GMT
Via: 1.1 varnish
Age: 108
Connection: keep-alive
X-Served-By: cache-hkg6823-HKG
X-Cache: HIT
X-Cache-Hits: 1
X-Timer: S1474003165.840989,VS0,VE0
Vary: Accept-Encoding
```

続いて`npm`のキャッシュをクリアしておきましょう。そうしないと、古いバージョンを見てしまうかもしれないからです。
```
$ sudo npm cache clean --force
```

それでは[CANDY RED](https://github.com/CANDY-LINE/candy-red)をアップデートしましょう。アップデートには、インストールと同様に15分~30分ほどかかる場合もあります。また、インストール時と同じように、`NODE_OPTS`も指定してください。

`309`は、Raspberry Pi3のRAM容量から計算した値です。Raspberry Pi2など他のボードでは、容量に応じて減らしてください。概ね全容量の20%~30%を指定します。例えば、512MBのRAMの場合は、`155`が目安となります。

```bash
$ sudo NODE_OPTS=--max-old-space-size=309 npm install -g --unsafe-perm candy-red
```

もし、なんらかの事情で特定のバージョンをインストールしたいときは、以下のようにバージョンを指定してください。

```bash
$ sudo NODE_OPTS=--max-old-space-size=309 npm install -g --unsafe-perm candy-red@バージョン
```

`バージョン`には、例えば`5.0.0`のような形式の文字列を指定します。無効な文字列を指定するとインストールできません。

### CANDY REDの動作確認

インストールが終わったら、[CANDY RED](https://github.com/CANDY-LINE/candy-red)が動作しているかを確認します。
```bash
$ sudo systemctl status candy-red
```

上記を実行して、以下のような結果が得られれば問題ありません。

    ● candy-red.service - CANDY RED Gateway Service, version:
       Loaded: loaded (/lib/systemd/system/candy-red.service; enabled)
       Active: active (running) since Wed 2016-01-27 02:11:31 UTC; 594ms ago
     Main PID: 3612 (bash)
       CGroup: /system.slice/candy-red.service
               ├─3612 bash /usr/local/lib/node_modules/candy-red/services/start_systemd.sh
               └─3618 node --max-old-space-size=128 /usr/local/lib/node_modules/candy-red/dist/index.j...

    Jan 27 02:11:31 my-ltepi systemd[1]: Starting CANDY RED Gateway Service, version:...
    Jan 27 02:11:31 my-ltepi systemd[1]: Started CANDY RED Gateway Service, version:.
    Jan 27 02:11:31 my-ltepi start_systemd.sh[3612]: logger: Activating Bluetooth...
    Jan 27 02:11:31 my-ltepi start_systemd.sh[3612]: Can't get device info: No such device
    Jan 27 02:11:31 my-ltepi start_systemd.sh[3612]: logger: Starting candy-red...

なお、この時点で、端末を再起動したときには、自動的に[CANDY RED](https://github.com/CANDY-LINE/candy-red)が起動するようになります。

続いて、candy-pi-lite サービスを再度起動しましょう。
```bash
$ sudo systemctl start candy-pi-lite
```

1〜2分ほどで、モデムが起動しインターネットに接続します。以下のコマンドを実行して接続状況を確認することができます。

```bash
$ ip route | grep default
```

以下のように`ppp0`と出ていれば成功です。
```
default dev ppp0  scope link
```

最後に[CANDY REDへのブラウザー接続](browsing-candy-red.md)を参照して、ブラウザーから接続してみましょう。

ブラウザーから以下のようにバージョンを見ることができます。

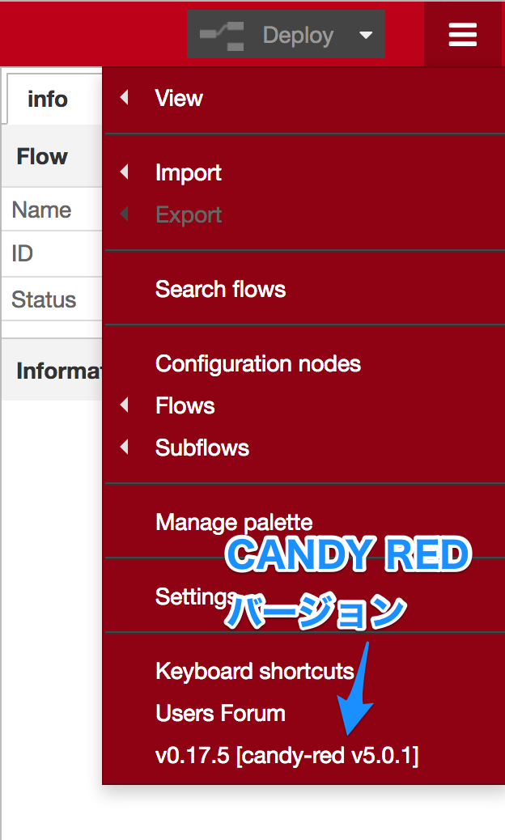
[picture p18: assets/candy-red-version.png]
CANDY REDバージョン


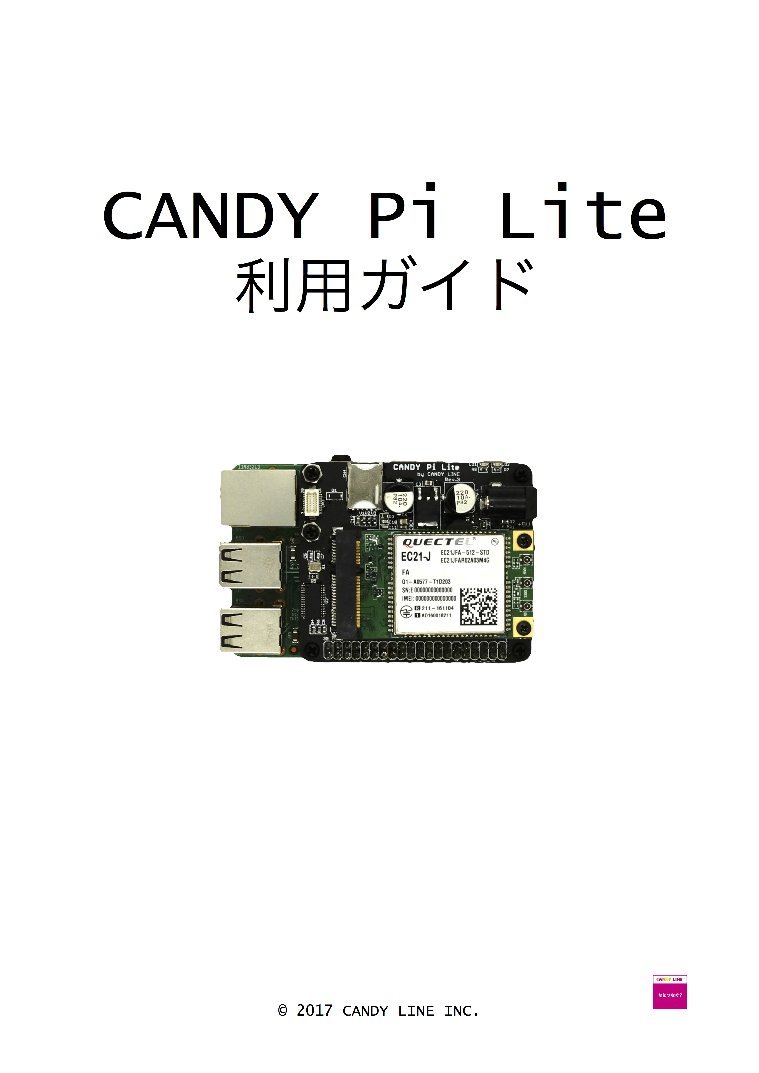
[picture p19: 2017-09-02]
cover.jpg

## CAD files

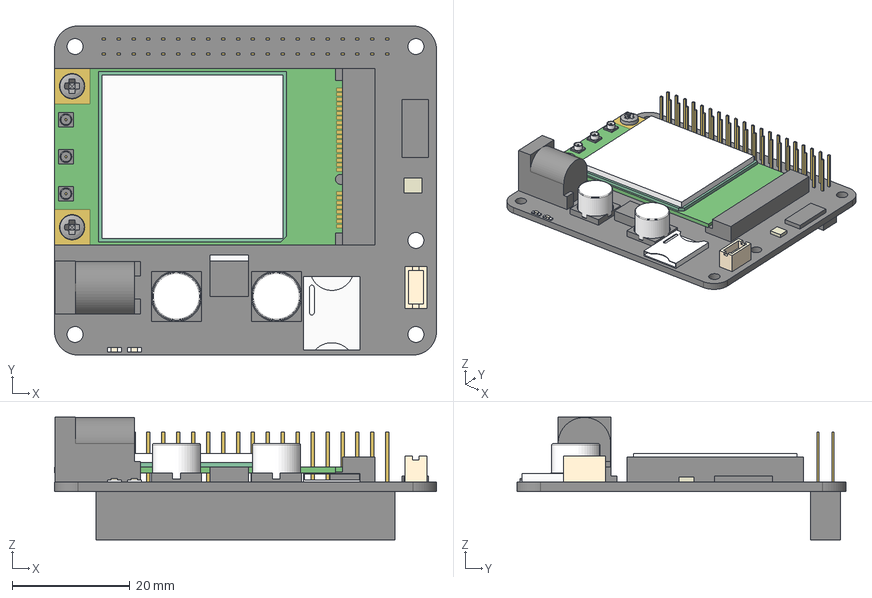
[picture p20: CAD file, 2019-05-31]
assets/candy-pi-lite-dimension.stp
65.0 x 56.0 x 20.9 mm
CANDY Pi Lite Rev3
EC21-J
FB-0204EB x 2

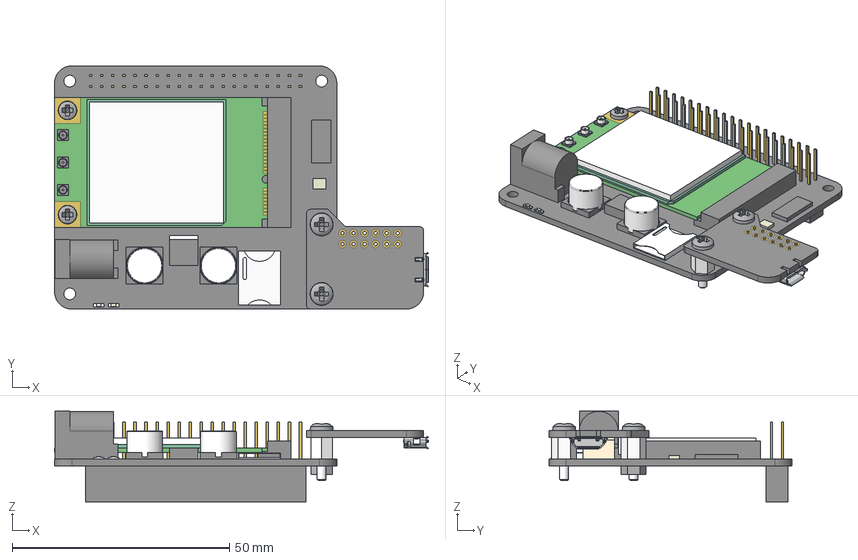
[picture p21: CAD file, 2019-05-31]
assets/candy-pi-lite-dimension_usbboard.stp
86.1 x 56.0 x 20.9 mm
CANDY Pi Lite Rev3
EC21-J
拡張基板_1
ZX62R-B-5P
FB-2604EB x 2
FB-0204EB x 2
BSB-2605E x 2
FNT-26EB-2

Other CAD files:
assets/candy-pi-lite-dimension.dxf
assets/candy-pi-lite-dimension_usbboard.dxf

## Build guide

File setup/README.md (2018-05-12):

# セットアップの仕方

CANDY Pi LiteやCANDY Pi Lite+のセットアップには、USB拡張ボードを使わない低速通信方式と、USB拡張ボードを取り付けてUSB接続する方式があります。
それぞれ必要となるものが異なりますので、ご注意ください。

* [CANDY Pi Lite+の組み立て](assemble-plus.md)
* [CANDY Pi Lite 3Gモデルの組み立て](assemble-3g.md)
* [CANDY Pi Lite LTEモデルの組み立て](assemble-lte.md)
* [低速通信を利用する場合の準備](uart.md)
* [USB接続を利用する場合の準備](usb.md)
* [OSイメージファイルを利用したセットアップ](etcher.md)
* [既存SDカードを利用したセットアップ](terminal.md)
* [インストールエラー](installation-errors.md)
* [CANDY REDへのブラウザー接続](bworsing-candy-red.md)
* [CANDY RED単体のインストール](candy-red.md)
* [Node-REDからの移行方法](node-red-migration.md)

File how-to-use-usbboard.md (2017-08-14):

# USB拡張ボードの使い方

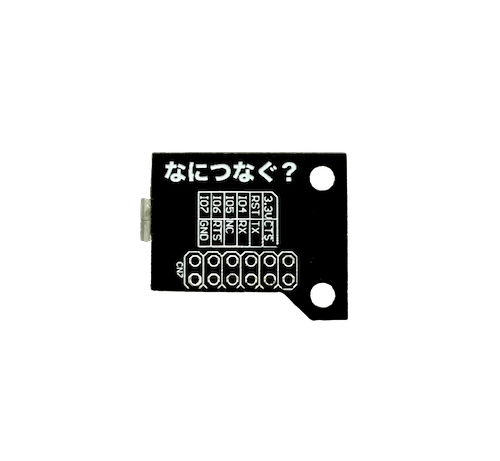
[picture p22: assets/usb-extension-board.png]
CANDY Pi Lite USB Extension Board


本章では、ラズパイから3G/LTE通信を行う方法以外の使い方を説明します。
この「なにつなぐ？」USB拡張ボードを取り付けて3G/LTE通信をラズパイから行う方法については、[セットアップの仕方（USB接続）](setup-usb.md)を参照してください。

## UARTシリアルを使う

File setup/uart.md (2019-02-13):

<!-- toc -->

# 低速通信を利用する場合の準備

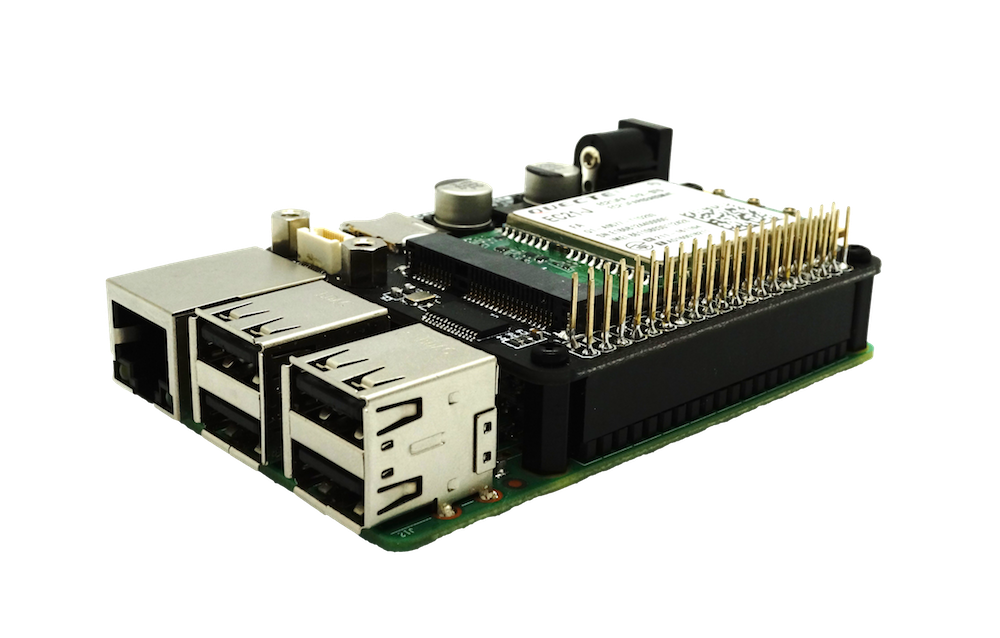
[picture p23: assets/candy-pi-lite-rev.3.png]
CANDY Pi Lite


本章では、USB拡張ボードを **使わないで** 3G/LTE通信を行うためのセットアップ方法を説明します。
USB拡張ボードを使う場合は、[セットアップの仕方（USB拡張ボード）](usb.md)をご覧ください。

## 用意するもの

USB拡張ボードを使わずにCANDY Pi Liteをご利用になる場合は、以下のものを用意しましょう。なお、ケーブル類やSIMカード、工具類はCANDY Pi Liteに付属しませんので、利用者の方がご用意ください。

- 組み立て済みのCANDY Pi Lite（アンテナも取り付けてください）
- 電源用USBケーブル、または5VACアダプター（内径：φ2.1mm、外径：φ5.5mm）
- LANケーブル
- nano（ナノ）サイズのSIMカード

*ご注意）ラズパイやASUS Tinker Board(またはS)に直接ログインする場合は、上記のほかディスプレイ、HDMIケーブル、USBキーボード、それにUSBマウスが必要です。*

### 電源用USBケーブル、または5VACアダプター

ラズパイやASUS Tinker Board(またはS)へ電源を供給するために、電源用USB2.0対応のタイプAオス-マイクロタイプBオスケーブルを利用します。5VのACアダプターをご利用の場合は、ACアダプターが対応する電流容量に注意しましょう。例えば、HDDやSSDなどの外部のUSBデバイスを取り付ける場合は、それらの電力も考慮した容量が必要です。電流容量が足りないACアダプターで運用すると、電力不足によってラズパイは停止または再起動を行うため、安定稼働を行うことができなくなってしまいます。

短時間での利用や開発時には、USBケーブルで電源供給することも可能です。このUSBケーブルは、パソコンとスマートフォンを繋げるようなタイプのケーブルを利用できます。
ただし、その場合でも電力不足を確認できた場合は、電流容量の大きいACアダプターの利用に切り替えてください。

**⚠️ DCジャックは、最大4Aまで対応しています。それより大きいACアダプターを利用しないようにしてください。**

### LANケーブル

LANケーブルは、ラズパイからインターネットへ接続したり、パソコンから接続できるようにするために使用するものです。
Wi-Fiの接続で代用することも可能です。ただし、本書ではラズパイでのWi-Fi設定方法は記載しませんので、関連するサイトや書籍をご覧の上ご利用ください。

### nano(ナノ)サイズのSIMカード

CANDY Pi Liteには、nano（ナノ）サイズのSIMカードを挿しこみます。金属面を下にして以下のような方向に挿し込んでください。

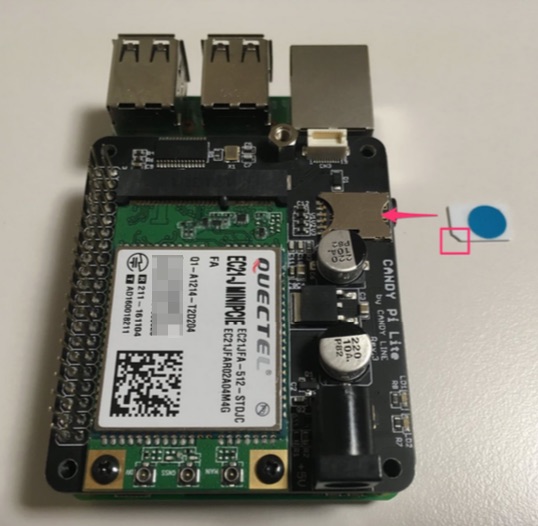
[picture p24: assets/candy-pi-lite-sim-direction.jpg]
How to insert a SIM card


# 次のステップ

準備ができましたら、「[セットアップの開始](terminal.md)」をご覧ください。

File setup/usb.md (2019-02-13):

<!-- toc -->

# USB接続を利用する場合の準備

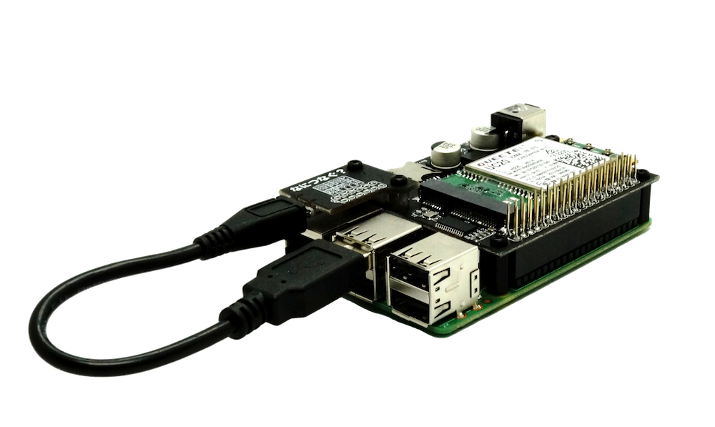
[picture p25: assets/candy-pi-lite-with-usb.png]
CANDY Pi Lite with USB Extension Board


本章では、このようにUSB拡張ボードを **取り付けた状態で** 3G/LTE通信を行うためのセットアップ方法を説明します。
USB拡張ボードを使わない場合は、[セットアップの仕方（低速通信）](uart.md)をご覧ください。

## 用意するもの

USB接続でCANDY Pi Liteをご利用になる場合は、以下のものを用意しましょう。なお、ケーブル類やSIMカード、工具類はCANDY Pi Liteに付属しませんので、利用者の方がご用意ください。

- 組み立て済みのCANDY Pi Lite（アンテナも取り付けてください）
- 電源用USBケーブル、または5VACアダプター（内径：φ2.1mm、外径：φ5.5mm）
- 通信用USBケーブル
- LANケーブル
- nano（ナノ）サイズのSIMカード
- 精密ドライバー(+, #1)

*ご注意）ラズパイまたはASUS Tinker Board(またはS)に直接ログインする場合は、上記のほかディスプレイ、HDMIケーブル、USBキーボード、それにUSBマウスが必要です。*

### 電源用USBケーブル、または5VACアダプター

ラズパイまたはASUS Tinker Board(またはS)へ電源を供給するために、電源用USB2.0対応のタイプAオス-マイクロタイプBオスケーブルを利用します。5VのACアダプターをご利用の場合は、ACアダプターが対応する電流容量に注意しましょう。例えば、HDDやSSDなどの外部のUSBデバイスを取り付ける場合は、それらの電力も考慮した容量が必要です。電流容量が足りないACアダプターで運用すると、電力不足によってラズパイは停止または再起動を行うため、安定稼働を行うことができなくなってしまいます。

短時間での利用や開発時には、USBケーブルで電源供給することも可能です。このUSBケーブルは、パソコンとスマートフォンを繋げるようなタイプのケーブルを利用できます。
ただし、その場合でも電力不足を確認できた場合は、電流容量の大きいACアダプターの利用に切り替えてください。

**⚠️ DCジャックは、最大4Aまで対応しています。それより大きいACアダプターを利用しないようにしてください。**

### 通信用USBケーブル

通信用のUSBケーブルは、電源用のUSBケーブルと同じタイプのものを利用できます。ただし、長いケーブルである必要はないので、例えば、千石電商で入手できる[USB2.0ケーブル(A-microB) 0.15m](https://www.sengoku.co.jp/mod/sgk_cart/detail.php?code=EEHD-4X7E)や、秋月電子通商で入手できる[ＵＳＢケーブル　Ａオス－マイクロＢオス　０．１５ｍ　Ａ](http://akizukidenshi.com/catalog/g/gC-09312/)などを利用することができます。

CANDY Pi LiteをラズパイまたはASUS Tinker Board(またはS)と組み合わせて3G/LTE通信を行う場合は、通信用USBケーブルを経由して電源供給を行うことはありません。このため、通信用USB接続のケーブルには大容量の電流を想定したケーブルを用いる必要はありません。

### LANケーブル

LANケーブルは、ラズパイまたはASUS Tinker Board(またはS)からインターネットへ接続したり、パソコンから接続できるようにするために使用するものです。
Wi-Fiの接続で代用することも可能です。ただし、本書ではラズパイでのWi-Fi設定方法は記載しませんので、関連するサイトや書籍をご覧の上ご利用ください。

### nano(ナノ)サイズのSIMカード

CANDY Pi Liteには、nano（ナノ）サイズのSIMカードを挿しこみます。金属面を下にして以下のような方向に挿し込んでください。

How to insert a SIM card

### 精密ドライバー(+, #1)

USB拡張ボードをCANDY Pi Liteに取り付けるためには、#1のプラス(+)の精密ドライバーが必要です。
ネジで固定しない場合、コネクター部分が破損したり、接続が不安定になったりしますので、必ずネジで固定するようにしてください。

### USB拡張ボードの取り付け

「[CANDY Pi Lite 3Gモデルの組み立て](assemble-3g.md)」、「[CANDY Pi Lite LTEモデルの組み立て](assemble-lte.md)」または「[CANDY Pi Lite+の組み立て](assemble-plus.md)」の図解をご覧になり、四角で囲んだ番号1から6を参照してください。

### USB接続の確認

USBが正しく接続されているか確認する場合は、USB拡張ボードの取り付けてUSBケーブルをラズパイまたはASUS Tinker Board(またはS)に差し込んでから、電源を入れてコマンドライン（ターミナル）にて、以下のコマンドを実行してください。

```
$ lsusb
Bus 001 Device 021: ID 05c6:9003 Qualcomm, Inc. Quectel UC20
Bus 001 Device 003: ID 0424:ec00 Standard Microsystems Corp. SMSC9512/9514 Fast Ethernet Adapter
Bus 001 Device 002: ID 0424:9514 Standard Microsystems Corp. SMC9514 Hub
Bus 001 Device 001: ID 1d6b:0002 Linux Foundation 2.0 root hub
```

ここで、IDの箇所をご覧いただき、数字とアルファベットの組み合わせが以下のどれかに当てはまるものがあれば、USBで接続ができている状態となります。なお、この例ではIDの数字とアルファベットの左隣に`Qualcomm, Inc. Quectel UC20`と出ていますが、モジュールによっては何も表示されない場合や文字列が異なる可能性もありますので、IDの値でご判断ください。

| 機種 | ID |
| --- | --- |
| CANDY Pi Lite 3G  | `05c6:9003` |
| CANDY Pi Lite LTE | `2c7c:0121` |
| CANDY Pi Lite+ | `2c7c:0125` |

# 次のステップ

準備ができましたら、「[セットアップの開始](terminal.md)」をご覧ください。

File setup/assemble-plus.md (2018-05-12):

<!-- toc -->

# CANDY Pi Lite+の組み立て

CANDY Pi Lite+の組み立てについては、以下の図解手順をご覧ください。上半分は標準の組み立てを、下半分は、USB拡張ボードを使った組み立てを表します。

なお、通信モジュールとアンテナとを取り付ける同軸ケーブルを取り外す際には、破損させないように注意してください。安全に取り外すには、[こちらのページ](/hardware/supplies.md)をご覧ください。

⚠️ **CANDY Pi Lite+のDCジャックは、初期ロットのASUS Tinker Board Sでは動作しないためお使いいただけません。2018年3月下旬以降に出荷されたASUS Tinker Board Sではご利用いただけます。**

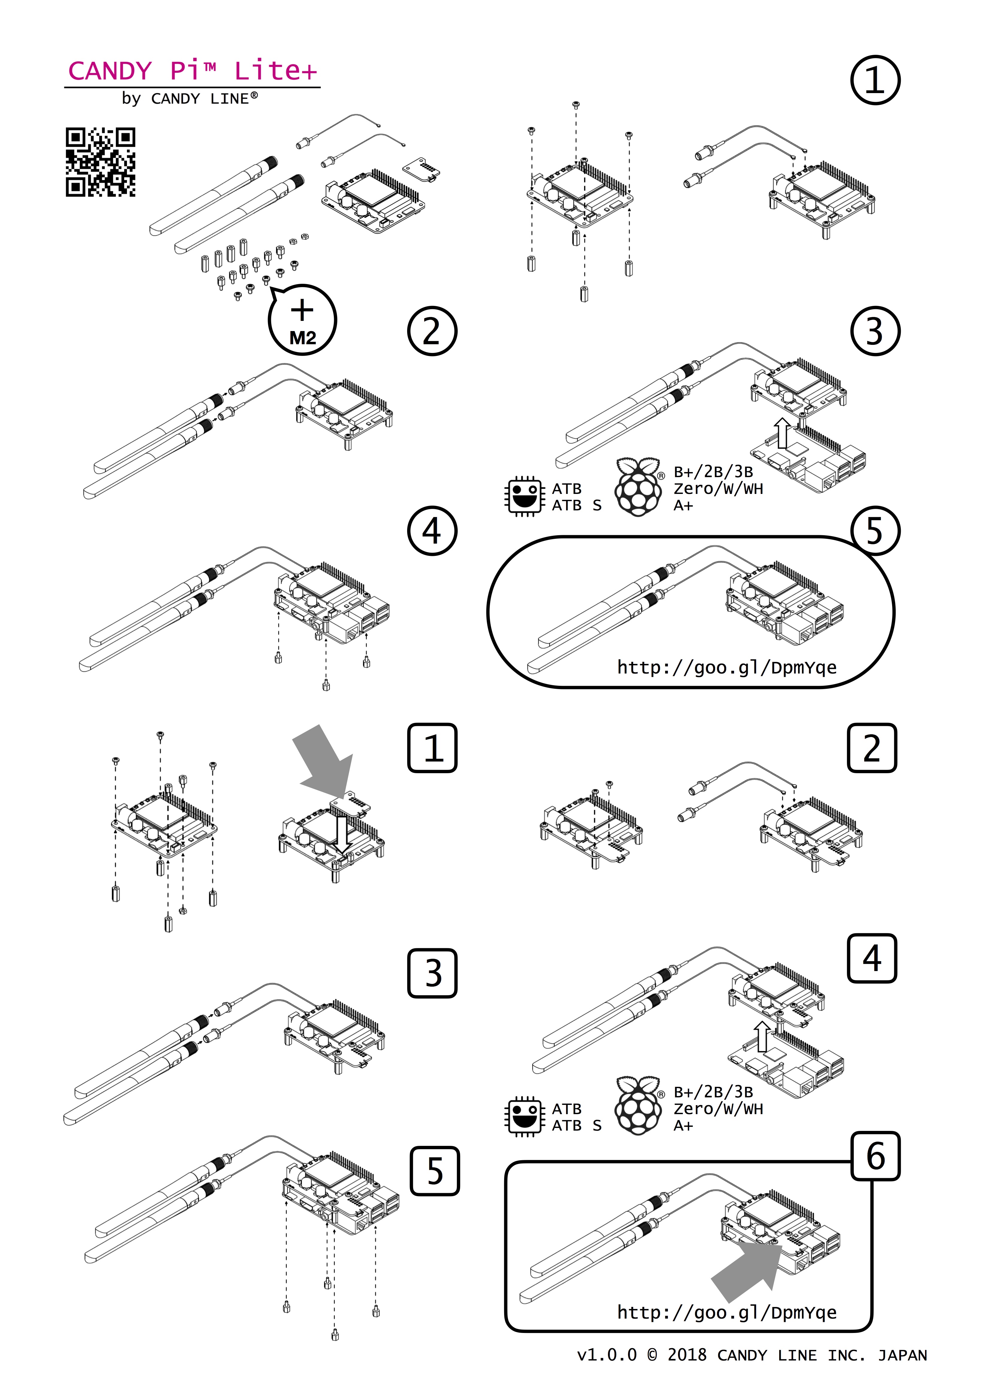
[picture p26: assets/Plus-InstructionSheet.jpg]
How to assemble(CANDY Pi Lite+)


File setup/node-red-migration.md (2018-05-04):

<!-- toc -->

# Node-REDからの移行方法

通常candy-pi-lite-serviceをインストールすると、プリインストールされているNode-REDはアンインストールされます。これは、[CANDY RED](https://github.com/CANDY-LINE/candy-red)をインストールするときに、プリインストールされているNode.jsも更新するためです。

**注意：RASPBIAN STRETCH LITEやTinker OSをお使いの場合には、もともとNode-REDは含まれておりません**

一見、Node-REDが使えなくなってしまうようですが、[CANDY RED](https://github.com/CANDY-LINE/candy-red)はNode-REDがベースとなっていますので、Node-REDの代わりとしてそのままお使いいただけます。また、GUIをお使いの場合、スタートメニューのProgrammingの項目からNode-REDを起動できなくなりますが、[CANDY RED](https://github.com/CANDY-LINE/candy-red)はOSが起動された時に自動的に開始されます。

このため、メニューから明示的にスタートを行う必要はありません。

しかし、Node-REDで作成されたフローや、追加されたノードをお持ちの場合は、CANDY REDでも使えるようにするため、データ移行の手順を実施する必要があります。

## フローの移行

フローの移行には2つの方法があります。一つは、ブラウザーでフローのインポート(Import)を行う方法、もう一つはコマンドラインで実行する方法です。ここでは、後者の方法を紹介します。

ラズパイにSSHでログインまたは、デスクトップ画面からLXTerminal（スタートメニューのSystem Toolsから選択できます）を起動し、以下のコマンドを実行してください。パスワードを聞かれたら、ラズパイのログインに使用したパスワードを入力してください。

    pi@raspberrypi: ~ $ sudo cp ~/.node-red/flows_${HOST_NAME}.json \
    /opt/candy-red/.node-red/flows_candy-red.json

(`pi@raspberrypi: ~ $`は入力する必要はありません)

このコマンドにより、Node-REDが作成したフローファイルをCANDY REDが利用するファイルの場所にコピーすることができます。

## ノードの移行

Node-REDにプリインストールされていないノードを追加していた場合、[CANDY RED](https://github.com/CANDY-LINE/candy-red)にも追加する必要があります。Node-REDで行った場合と同じように、npmコマンドを使います。違いは、コマンドを実行するディレクトリーと`sudo`と`--unsafe-perm`を用いることです。`--unsafe-perm`は、全てのノードで必要になるとは限りませんが、ノードの種類によってはファイルのコピーにおいてエラーとなる場合がありますので、指定するようにしてください。

以下では、node-red-contrib-slackを[CANDY RED](https://github.com/CANDY-LINE/candy-red)に追加する例を示します。

    pi@raspberrypi: ~ $ cd /opt/candy-red/.node-red
    pi@raspberrypi: /opt/candy-red/.node-red $ sudo npm install --unsafe-perm node-red-contrib-slack
    pi@raspberrypi: /opt/candy-red/.node-red $ sudo systemctl restart candy-red

インストールしたノードを有効にするために、サービスを起動しなおす必要があります。これを上記3行目で行っています。単純に再起動する方法でも問題ありません。

## CANDY REDでのノード追加について

今後CANDY REDで新しいノードを追加するときは、上記のように`/opt/candy-red/.node-red`ディレクトリーで`sudo`と`--unsafe-perm`をつけてインストールを行う必要があります。通常のドキュメントでは、Node-RED向けのディレクトリー`~/.node-red`で説明がありますので読み替えるようにお願いいたします。

詳細については、[CANDY REDでのノード設定](/configuration/)をご覧ください。

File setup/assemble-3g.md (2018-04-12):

<!-- toc -->

# 3Gモデルの組み立て

3Gモデルの組み立てについては、以下の図解手順をご覧ください。上半分は標準の組み立てを、下半分は、USB拡張ボードを使った組み立てを表します。

なお、通信モジュールとアンテナとを取り付ける同軸ケーブルを取り外す際には、破損させないように注意してください。安全に取り外すには、[こちらのページ](/hardware/supplies.md)をご覧ください。

⚠️ **CANDY Pi LiteのDCジャックは、初期ロットのASUS Tinker Board Sでは動作しないためお使いいただけません。2018年3月下旬以降に出荷されたASUS Tinker Board Sではご利用いただけます。**

3Gモデルの場合、アンテナは1本だけでも通信可能です。もう1本のアンテナは、ダイバーシティアンテナとなりますので、受信感度を上げるために使用することが可能です。取り付ける本数につきましては、設置場所や状況によりご利用者の方にてご判断ください。

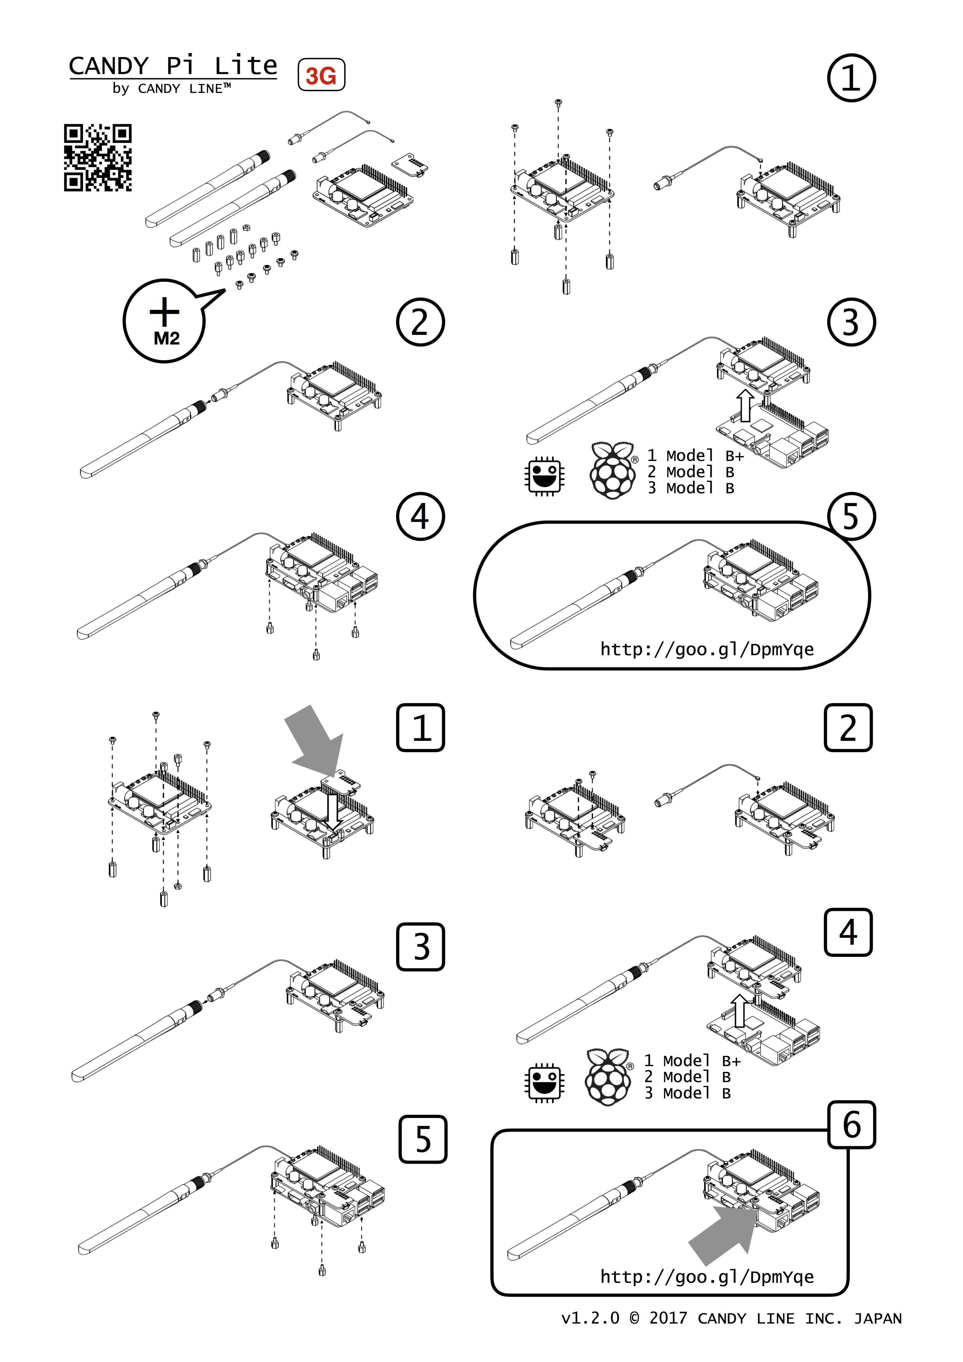
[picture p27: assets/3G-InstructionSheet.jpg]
How to assemble(3G)


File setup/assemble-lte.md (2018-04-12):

<!-- toc -->

# LTEモデルの組み立て

LTEモデルの組み立てについては、以下の図解手順をご覧ください。上半分は標準の組み立てを、下半分は、USB拡張ボードを使った組み立てを表します。

なお、通信モジュールとアンテナとを取り付ける同軸ケーブルを取り外す際には、破損させないように注意してください。安全に取り外すには、[こちらのページ](/hardware/supplies.md)をご覧ください。

⚠️ **CANDY Pi LiteのDCジャックは、初期ロットのASUS Tinker Board Sでは動作しないためお使いいただけません。2018年3月下旬以降に出荷されたASUS Tinker Board Sではご利用いただけます。**

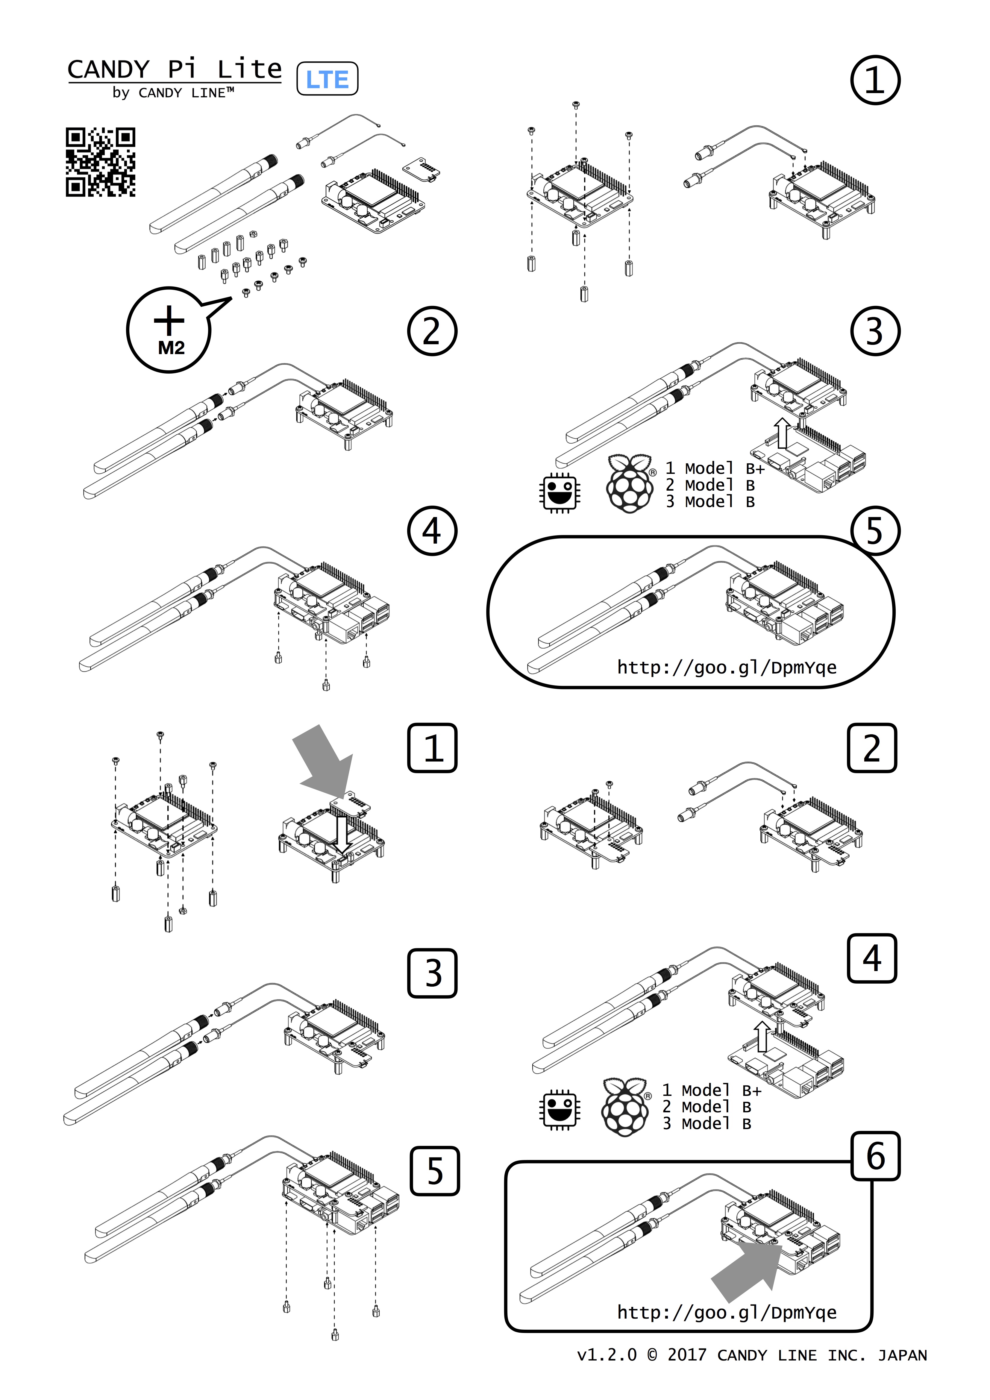
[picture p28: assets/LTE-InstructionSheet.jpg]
How to assemble(LTE)


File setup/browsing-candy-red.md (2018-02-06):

<!-- toc -->

# CANDY REDへのブラウザー接続

CANDY Pi Liteのセットアップを行うと、[CANDY RED](https://github.com/CANDY-LINE/candy-red)が有効になっていますので、ブラウザーから接続してみましょう。ラズパイがつながっている有線または無線LANと同じネットワークにあるコンピューターのブラウザーで以下のアドレスを入力してページを表示させてみてください。
```
http://raspberrypi.local:8100
```
もしラズパイのホスト名を変更していた場合は、「ホスト名.local」を「raspberrypi.local」の代わりに指定します。名前でつながらないときは、IPアドレスを指定しましょう。

ASUS Tinker Board(またはS)をお使いの場合は、`raspberrypi.local`の代わりに`tinkerboard.local`を使用できます。
```
http://tinkerboard.local:8100
```

ログイン画面では、ラズパイまたはASUS Tinker Board(またはS)にログインするユーザーとパスワードを入力してください。

ご注意）ラズパイまたはASUS Tinker Board(またはS)のデフォルトパスワードを変更されていない場合は、悪意のある第三者に勝手に使用される恐れがありますから **必ず** 変更するようにしてください。

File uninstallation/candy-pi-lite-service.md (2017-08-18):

<!-- toc -->

# candy-pi-lite サービスのアンインストール

ホームディレクトリーに移りアンインストールのスクリプトを実施してください。
```bash
$ cd ~
$ sudo /opt/candy-line/candy-pi-lite/uninstall.sh
```
このコマンドでは、[CANDY RED](https://github.com/CANDY-LINE/candy-red)は削除されません。[CANDY RED](https://github.com/CANDY-LINE/candy-red)を削除する場合は、「[CANDY REDのアンインストール](candy-red.md)」をご覧ください。

実行すると以下のように表示されます。
```bash
$ cd ~
$ sudo /opt/candy-line/candy-pi-lite/uninstall.sh
Removed symlink /etc/systemd/system/multi-user.target.wants/candy-pi-lite.service.
[INFO] candy-pi-lite has been uninstalled
Uninstalling candy-board-qws:
  Successfully uninstalled candy-board-qws
Uninstalling candy-board-cli:
  Successfully uninstalled candy-board-cli
[ALERT] *** Please reboot the system! (enter 'sudo reboot') ***
```

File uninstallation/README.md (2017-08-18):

# アンインストールの仕方

CANDY Pi Liteをセットアップした際にインストールされたソフトウェアは、以下の方法でアンインストールできます。

* [candy-pi-lite サービスのアンインストール](candy-pi-lite-service.md)
* [CANDY REDのアンインストール](candy-red.md)

ただし、以下の設定は上記の方法では元に戻されません。

1. `/boot/config.txt`に追加された設定。元に戻したいときは、`/boot/config.txt.bak`を`/boot/config.txt`置き換えてください。`/boot/config.txt`に適用された変更は失われますのでご注意ください。
1. `/boot/overlays/sc16is752-spi0-ce1.dtbo`ファイル。不要な場合は、手動で削除してください。

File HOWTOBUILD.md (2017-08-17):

# Install

```
$ npm install
```

# Plugin Installation

```
$ npm run install
```

# Serve this book

```
$ npm run serve
```

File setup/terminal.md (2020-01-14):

<!-- toc -->

# 既存SDカードを利用したセットアップ

**👉 本手順は、ラズパイ、ASUS Tinker Board(またはS)共通の手順です**

**👉 ラズパイをご利用の方は、セットアップ済みのRaspbian Stretch LiteベースのOSイメージもご利用いただけます。方法は[こちらのブログ記事](https://candy-line.tumblr.com/post/167761781228/candy-pi-lite-os-image-etcher)や、「[OSイメージファイルを利用したセットアップ](/setup/etcher.md)」をご覧ください**

## コマンド入力の準備

最初にLANケーブルの一方をラズパイまたはASUS Tinker Board(またはS)に、もう一方をブロードバンドルーターに接続してインターネットに通信できる状態にしてください。電源はこの時点ではまだ入れないでください。

すでにラズパイまたはASUS Tinker Board(またはS)にてWi-Fiの設定を行っており、インターネットを利用できている場合は、Wi-Fi経由でこれ以降の作業を行うことも可能です。ただし、Wi-Fi環境では、無線状況により接続が不安定になる場合もありますので、Wi-Fi環境でうまくいかない場合は、LANケーブルを使ってインストールをお試しください。

次に、CANDY Pi Liteを取り付けたラズパイまたはASUS Tinker Board(またはS)に、SIMカードを差し込みます。SIMカードは、金属面を下向きにして取り付けます。

最後に、通信用USBケーブルでCANDY Pi LiteとラズパイまたはASUS Tinker Board(またはS)を接続します。

これで準備が整いました。それでは、ラズパイまたはASUS Tinker Board(またはS)に電源用USBケーブルを接続してラズパイを起動させましょう。

ラズパイまたはASUS Tinker Board(またはS)が起動したらログインをします。コマンドを入力できる環境を次のどちらかの方法で用意しましょう。

- デスクトップ画面（PIXEL環境）をお使いの場合は、ログインした後にスタートメニューのSystem Toolsから「LXTerminal」を選択して起動してください
- SSH環境をお使いになる場合は、SSHコマンドにてログインしてください

## ターミナルでの作業

ターミナルが開いたら、試しに以下のようなcURLコマンドを実行してみましょう。

```bash
$ curl -i -s -L --head https://www.candy-line.io/ | grep "200 OK"
```

下記のように`HTTP/1.1 200 OK`と出ていれば問題ありません。
```bash
HTTP/1.1 200 OK
```

続いてOSの状態が古い場合は、必要に応じて新しい状態に更新しましょう。
もしこのタイミングで更新したくなければ、この手順を飛ばしても構いません。
ただし、あまりにも古いOSであれば動作しない可能性もありますので、その場合は更新することを検討してください。

**注意：意図しないパケット消費を防ぐため、以下のコマンドを実行する前にモバイルネットワークに接続していないか確認しましょう。**

```bash
$ sudo apt-get upgrade -y
```
なお、この処理には、SDカードのクラス(読み書き速度)、更新するデータ量、あるいはネットワーク環境によりますが30分〜1時間以上かかることがあります。

それでは、GitHub上にあるスクリプトをダウンロードしてインストールします。

**注意：以下のコマンドは、プリインストールされているNode-REDを削除し、[CANDY RED](https://github.com/CANDY-LINE/candy-red)に置き換えます（Node-REDと同じ使い方をすることができますのでNode-REDの代わりとしてお使いいただけます）。Node.jsを更新するため、プリインストールされているNode-REDを残しておくことができないので削除しています。既存のフローをお持ちの場合は、[Node-REDからの移行方法](node-red-migration.md)を参照してください。**

### APN指定をしてセットアップ

以下のコマンドを実行すると（`git.io`もGitHubの管理するドメインの1つです）、接続先のAPNを指定してセットアップを開始します。なお、[`candy-pi-lite-service v1.8.0`](https://forums.candy-line.io/t/v1-8-0/90)以降からは、[有線LAN固定IP設定](/configuration/ether-static-ip.md)を特別な設定なくご利用頂けます。

`BOOT_APN`には、あらかじめ用意されているAPN設定を指定することができます。`BOOT_APN`を省略することもでき、その場合は、`soracom.io`として扱われます。

```bash
$ curl -sL https://git.io/v7bXx | sudo BOOT_APN=<apn名> bash
```
`<apn名>`には、現在[プリセットされたAPNの一覧](/configuration/apn-list.md)に記載された値を指定することができます。

例えば、IIJモバイル/タイプIのIPv4/IPv6接続を指定するときは、以下のように指定します。

```bash
$ curl -sL https://git.io/v7bXx | sudo BOOT_APN=iijmobile.biz-ipv4v6 bash
```

### デフォルトのAPNを指定してセットアップ

`BOOT_APN`を省略すると、デフォルトのAPNを指定した状態でセットアップします。

```bash
$ curl -sL https://git.io/v7bXx | sudo bash
```

### 指定したバージョンのcandy-pi-lite-serviceをセットアップ

また、candy-pi-lite-serviceの特定のバージョンを利用する場合は、以下のようにバージョンを指定することができます。なお、[CANDY RED](https://github.com/CANDY-LINE/candy-red)については、常に最新のバージョンのものだけを利用することができます。
```bash
$ VERSION=1.2.3 && \
  curl -sL https://raw.githubusercontent.com/CANDY-LINE/candy-pi-lite-service/${VERSION}/install.sh | \
  sudo bash
```

**注意：すでにcandy-pi-lite-serviceをインストールしている場合にインストールをしようとしてもインストールされません。エラーメッセージが出て、アンインストールするコマンドを実行するように促されます。このため、必ず一度アンインストールを行ってからインストールを行ってください。**

### セットアップコマンドの実施結果

実行すると以下のように表示されます。

    [INFO] Installing command lines to /opt/candy-line/candy-pi-lite/bin...
              :
              :
    [INFO] Installing CANDY RED...
              :
              :
    [INFO] candy-pi-lite service has been installed
    [ALERT] *** Please reboot the system (enter 'sudo reboot') ***

なおインストールは早ければ15分程度で終わりますが、状況によっては1~2時間以上かかる場合もありますので、処理が止まっているように見えても途中で中断をしないようにしてください。
インストールに失敗したときは、[インストールエラー](installation-errors.md)の説明を参照してください。

## 動作確認

インストールした後は、以下のコマンドを実行して再起動させましょう。

**注意：ソラコムのSIMをお使いの場合は、挿し込んでいるSIMが「使用中」になっているかご確認ください。「休止中」の場合は、携帯電話ネットワークに接続できず、オレンジのLEDが点滅しません。**

```bash
$ sudo reboot
```

再起動後しばらくすると、CANDY Pi LiteのオレンジのLEDが点滅します。これはモデムが起動していることを表しています。

CANDY Pi LiteのLEDが点滅していれば、セットアップは完了です！

なお、接続方法によって次のようにLEDの明滅パターンが異なります。詳細は、[LED設定]((/configuration/led.md))をご覧ください。

[CANDY REDへのブラウザー接続](browsing-candy-red.md)のページを参照して、[CANDY RED](https://github.com/CANDY-LINE/candy-red)を動かしてみましょう。
あるいは、すでにラズパイまたはASUS Tinker Board(またはS)で動作するアプリケーションをお持ちの場合は、動かしてみましょう。

もし圏外だったり、アンテナが接続されていなかったりした場合は、モデムは起動できません。LEDの表示はオレンジ色の1つのみ点灯します。
うまく動かない時は[トラブルシューティング](/troubleshooting.md)のページにモデムが起動しない場合の対処策をまとめていますので、ご確認ください。

また、既定の設定では、ソラコムのAPN設定が反映されます。このため、お使いのSIMカードがソラコム以外のものである場合は、[APN変更方法](/configuration/apn.md)に記載の方法で変更する必要があります。

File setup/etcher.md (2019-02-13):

<!-- toc -->

# OSイメージファイルを利用したセットアップ

**👉 OSイメージは、ラズパイ専用です。ASUS Tinker Board(またはS)ではご利用になれません**

**👉 すでにお持ちのSDカードにインストールする場合は[こちら](/setup/terminal.md)をご覧ください**

## OSイメージのダウンロード

まずは、CANDY Pi Lite向けセットアップ済みのRaspbian OSイメージをダウンロードしましょう。OSイメージは、以下のページから数字がもっとも大きい最新のバージョンを探してダウンロードしましょう。

```
https://forums.candy-line.io/tags/os
```

以下の画面の時点では、「1.3.0」が最新となりますので、その項目をクリックします。

_⚠️実際の画面では「1.3.0」よりも新しい場合がありますので、その場合は最新のバージョンをクリックしてください_
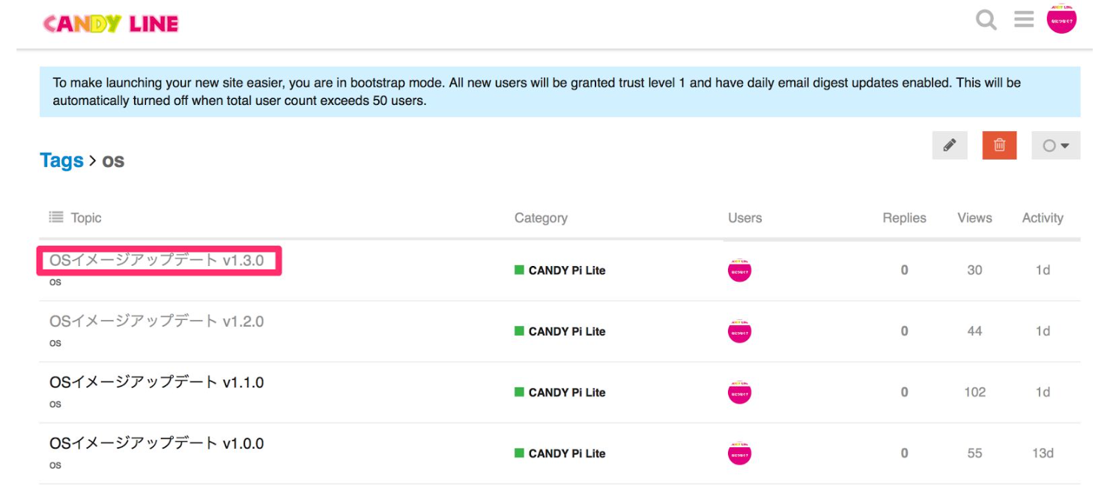
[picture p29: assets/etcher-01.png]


すると、以下のようなページが出現します。
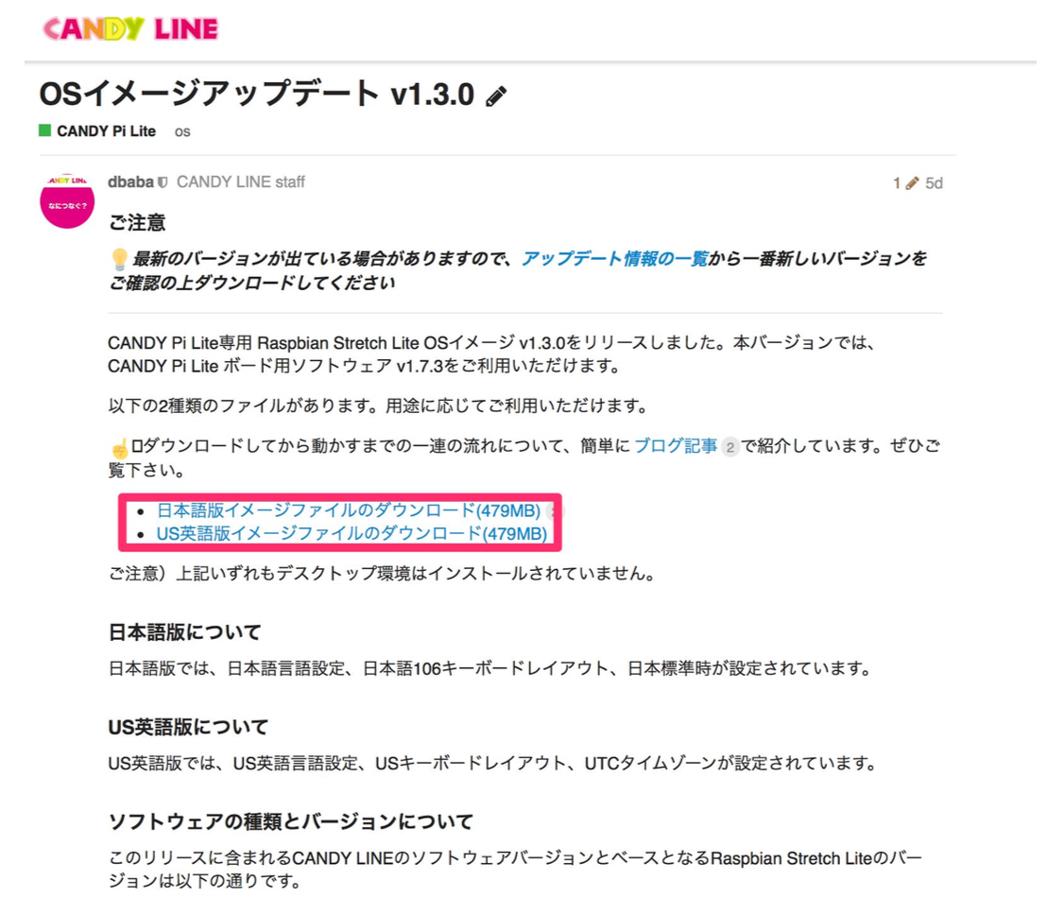
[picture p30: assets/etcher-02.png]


四角で囲ったところから、「日本語版イメージファイル」または「US英語版イメージファイル」をダウンロードすることができます。

光回線の環境であれば、通常5分〜15分程度でダウンロード可能です。また、上記記載にもありますが、[ブログ記事](https://candy-line.tumblr.com/post/167761781228/candy-pi-lite-os-image-etcher)上でもOSイメージの準備方法を記載していますので、より細かいOSイメージの利用方法についてはブログも参照してください。

## マイクロSDカードの準備

OSイメージをマイクロSDに書き込むためには、[balenaEtcher](https://balena.io)を利用します。balenaEtcherは、Windows、macそれにLinuxデスクトップで利用することができます。

こちらのサイトでソフトウェアをダウンロードしてインストールしましょう。
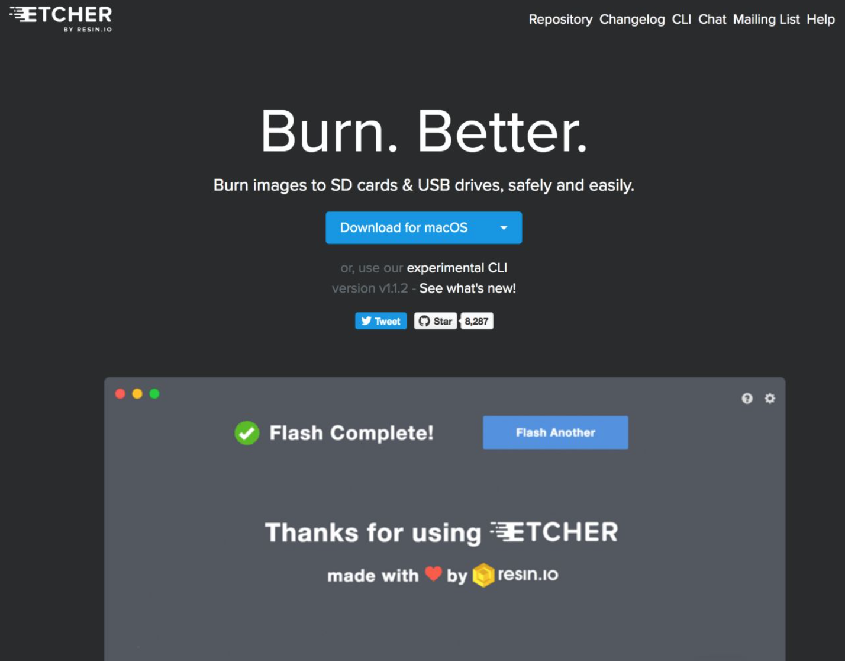
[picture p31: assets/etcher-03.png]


ダウンロードとインストールができたら、balenaEtcherを起動しましょう。

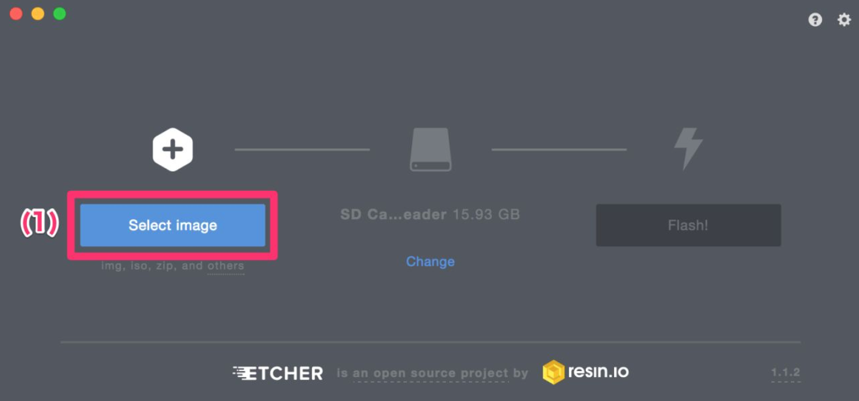
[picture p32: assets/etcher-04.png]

最初に、イメージファイルを選択します。ダウンロードしたイメージファイルを「Select image」をクリックして選択します。 マイクロSDカードをパソコンに取り付けると、「Flash!」を押せるようになります。

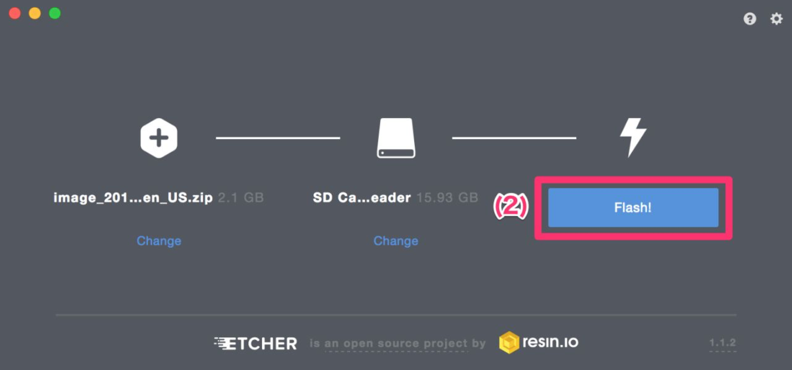
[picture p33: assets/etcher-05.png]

書き込みには、5分程度かかります。また、書き込みの際に、特権ユーザーのパスワードが聞か れる場合がありますので、その場合は、パスワードの入力を行います。 書き込みが終わったら、次のステップに進みます。

## 動作確認

書き込みが終わったら、ラズパイにマイクロSDカードを差し込んで起動してみましょう。

**注意：ソラコムのSIMをお使いの場合は、挿し込んでいるSIMが「使用中」になっているかご確認ください。「休止中」の場合は、携帯電話ネットワークに接続できず、オレンジのLEDが点滅しません。**

電源を入れてからしばらくすると、CANDY Pi LiteのオレンジのLEDが点滅します。これはモデムが起動していることを表しています。

CANDY Pi LiteのLEDが点滅していれば、セットアップは成功です！

[CANDY REDへのブラウザー接続](browsing-candy-red.md)のページを参照して、[CANDY RED](https://github.com/CANDY-LINE/candy-red)を動かしてみましょう。
あるいは、すでにラズパイで動作するアプリケーションをお持ちの場合は、動かしてみましょう。

もし圏外だったり、アンテナが接続されていなかったりした場合は、モデムは起動できません。LEDの表示はオレンジ色の1つのみ点灯します。
うまく動かない時は[トラブルシューティング](/troubleshooting.md)のページにモデムが起動しない場合の対処策をまとめていますので、ご確認ください。

また、既定の設定では、ソラコムのAPN設定が反映されます。このため、お使いのSIMカードがソラコム以外のものである場合は、[APN変更方法](/configuration/apn.md)に記載の方法で変更する必要があります。

## SSHについて

OSイメージを書き込んだ初期状態では、**SSHが有効になっていません**。これは、OSイメージに書き込まれたパスワードがラズパイのデフォルト情報と同じであるため、SSHを有効にしてしまうと思わぬトラブルが発生してしまうためです。このため、SSHをご利用になるためには、通常のRaspbianと同様に、マイクロSDカードの`boot`フォルダーにファイル名`ssh`のファイルを作成してからラズパイを起動してください。ファイルの中身は無関係ですので、空のデータでもダミーのデータでも構いません。

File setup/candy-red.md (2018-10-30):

<!-- toc -->

# CADNY RED単体のインストール

candy-pi-lite サービスをインストールすると、ラズパイ上にNode-REDベースのフローエディターである[CANDY RED](https://github.com/CANDY-LINE/candy-red)もインストールされます。通常のNode-REDとしての機能のほか、CANDY EGGクラウドサービスと連携して手軽にクラウドとのやりとりを行うアプリケーションを作成することができます。

> ### <☝️ワンポイント> Node-REDに馴染みのない方にオススメの書籍
>
> 2017年に以下の2種類の書籍が発売されました。Node-REDの解説がされています。CANDY REDはNode-REDをベースにしているため、これらの書籍が参考になります。
>
> - プログラミング初心者の方へ：[つないで つないで プログラミング Node-REDでつくる初めてのアプリ](https://www.amazon.co.jp/%E3%81%A4%E3%81%AA%E3%81%84%E3%81%A7-%E3%83%97%E3%83%AD%E3%82%B0%E3%83%A9%E3%83%9F%E3%83%B3%E3%82%B0-Node-RED%E3%81%A7%E3%81%A4%E3%81%8F%E3%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)
> - プログラミングの心得のある方へ：[はじめてのNode‐RED](https://www.amazon.co.jp/%E3%81%AF%E3%81%98%E3%82%81%E3%81%A6%E3%81%AENode%E2%80%90RED-I%E3%83%BB-BOOKS-Node%E2%80%90RED%E3%83%A6%E3%83%BC%E3%82%B6%E3%83%BC%E3%82%B0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,204,203,200_QL40_)

初回インストール時に[CANDY RED](https://github.com/CANDY-LINE/candy-red)を **インストールしていない場合(`CANDY_RED=0`を指定してインストールした場合)** 以下の手順で追加することができます。すでにインストールされているときは、以下の手順は不要となります。

### CANDY REDアプリケーションのインストール

まず最初に、candy-pi-lite サービスを停止し、LANケーブルまたはWiFiでインターネットに接続します。これは、ダウンロードにかかる通信を携帯電話ネットワークではなく有線・無線LANにて行うようにするためです。

はじめに、以下のコマンドを実行してcandy-pi-lite サービスを停止します。

```bash
$ sudo systemctl stop candy-pi-lite
```

続いて、ネットワークの確認を行います。ラズパイにコマンドラインからアクセスして、以下のコマンドを実行します。

```bash
$ curl --head https://registry.npmjs.org
```

以下のように結果が返って来るようであれば、正しくインターネットに接続できています。

```
HTTP/1.1 200 OK
server: CouchDB/1.5.0 (Erlang OTP/R16B03)
Content-Type: application/json
Cache-Control: max-age=300
Content-Length: 262
Accept-Ranges: bytes
Date: Fri, 16 Sep 2016 05:19:25 GMT
Via: 1.1 varnish
Age: 108
Connection: keep-alive
X-Served-By: cache-hkg6823-HKG
X-Cache: HIT
X-Cache-Hits: 1
X-Timer: S1474003165.840989,VS0,VE0
Vary: Accept-Encoding
```

続いて、Node.jsを入れ替えます。Raspbian 4.1以降ではNode-REDがプリインストールされていますのでNode.jsもすでに入っています。しかし、[CANDY RED](https://github.com/CANDY-LINE/candy-red)インストール時に追加するアドオンを用意するときに、プリインストールされたNode.jsでは解決できないエラーが発生してしまいます。これを避けるため、Node.jsを入れ替えるようにします。

Raspberry Pi Model B+をお使いの場合は、以下のコマンドを実行します。
```bash
$ sudo apt-get update -y
$ sudo apt-get upgrade -y
$ cd /tmp
$ ARMv6_NODEJS_VERSION="6.11.2"
$ wget https://nodejs.org/dist/v${ARMv6_NODEJS_VERSION}/node-v${ARMv6_NODEJS_VERSION}-linux-armv6l.tar.gz
$ tar zxf node-v${ARMv6_NODEJS_VERSION}-linux-armv6l.tar.gz
$ cd node-v${ARMv6_NODEJS_VERSION}-linux-armv6l/
$ sudo cp -R * /usr/local/
$ sudo apt-get install -y python-dev python-rpi.gpio bluez libudev-dev
```

Raspberry Pi 2と3をお使いの場合は、以下のコマンドを実行します。
```bash
$ sudo apt-get update
$ sudo apt-get upgrade
$ curl -sL https://deb.nodesource.com/setup_6.x | sudo bash -
$ sudo apt-get install -y python-dev python-rpi.gpio bluez nodejs libudev-dev
```

続いて`npm`のキャッシュをクリアしておきましょう。そうしないと、古いバージョンを見てしまうかもしれないからです。
```
$ sudo npm cache clean --force
```

それでは[CANDY RED](https://github.com/CANDY-LINE/candy-red)をインストールしましょう。インストールには、15分~30分ほどかかります。`--max-old-space-size=128`には、Node.jsプロセスが割り当てられる上限のメモリーサイズを指定しましょう。デフォルトでは512MiBとなり、Raspberry Piの機種によっては、大きすぎる値になる場合がありますので、最大容量よりも少ない値となるように指定しましょう。この例では、128を割り当てています。

```bash
$ sudo NODE_OPTS=--max-old-space-size=128 npm install -g --unsafe-perm candy-red
```

### CANDY REDの動作確認

それでは動作しているかを確認します。
```bash
$ sudo systemctl status candy-red
```

上記を実行して、以下のような結果が得られれば問題ありません。

    ● candy-red.service - CANDY RED Gateway Service, version:
       Loaded: loaded (/lib/systemd/system/candy-red.service; enabled)
       Active: active (running) since Wed 2016-01-27 02:11:31 UTC; 594ms ago
     Main PID: 3612 (bash)
       CGroup: /system.slice/candy-red.service
               ├─3612 bash /usr/local/lib/node_modules/candy-red/services/start_systemd.sh
               └─3618 node --max-old-space-size=128 /usr/local/lib/node_modules/candy-red/dist/index.j...

    Jan 27 02:11:31 my-ltepi systemd[1]: Starting CANDY RED Gateway Service, version:...
    Jan 27 02:11:31 my-ltepi systemd[1]: Started CANDY RED Gateway Service, version:.
    Jan 27 02:11:31 my-ltepi start_systemd.sh[3612]: logger: Activating Bluetooth...
    Jan 27 02:11:31 my-ltepi start_systemd.sh[3612]: Can't get device info: No such device
    Jan 27 02:11:31 my-ltepi start_systemd.sh[3612]: logger: Starting candy-red...

なお、この時点で、端末を再起動したときには、自動的に[CANDY RED](https://github.com/CANDY-LINE/candy-red)が起動するようになります。

続いて、candy-pi-lite サービスを再度起動しましょう。
```bash
$ sudo systemctl start candy-pi-lite
```

1〜2分ほどで、モデムが起動しインターネットに接続します。以下のコマンドを実行して接続状況を確認することができます。

```bash
$ ip route | grep default
```

以下のように`ppp0`と出ていれば成功です。
```
default dev ppp0  scope link
```

最後に[CANDY REDへのブラウザー接続](browsing-candy-red.md)を参照して、ブラウザーから接続してみましょう。

ノードの追加などの方法は[CANDY REDでのノード設定](/configuration/)をご覧ください。

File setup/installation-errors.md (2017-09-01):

<!-- toc -->

# インストールに失敗した時は

## `registry.npmjs.org`へ接続できない

環境によっては、インストール実施中に以下のようなメッセージで終了することがあります。

    npm ERR! network getaddrinfo ENOTFOUND registry.npmjs.org
    npm ERR! network This is most likely not a problem with npm itself
    npm ERR! network and is related to network connectivity.
    npm ERR! network In most cases you are behind a proxy or have bad network settings.
    npm ERR! network
    npm ERR! network If you are behind a proxy, please make sure that the
    npm ERR! network 'proxy' config is set properly.  See: 'npm help config'

    > candy-red@2.8.0 preuninstall /usr/lib/node_modules/candy-red
    > ./uninstall.sh

    ls: cannot access /usr/lib/node_modules/candy-red/services/start_*: No such file or directory

    [ERROR] The service candy-red isn't installed yet.

    npm ERR! Please include the following file with any support request:
    npm ERR!     /root/npm-debug.log
    [INFO] Installing system service ...
    Created symlink from /etc/systemd/system/multi-user.target.wants/ltepi2.service to /lib/systemd/system/ltepi2.service.
    [INFO] candy-pi-lite service has been installed
    [ALERT] *** Please reboot the system (enter 'sudo reboot') ***

このような場合は、ご利用のネットワーク環境にて一時的にインターネットへ接続できていない可能性があります。
その結果、[CANDY RED](https://github.com/CANDY-LINE/candy-red)のインストールには失敗しております。しかし、candy-pi-lite-serviceのサービス自体はインストールできています。

この場合は、[CANDY REDのインストール方法](CANDY REDのインストール方法.md)をご覧いただき、[CANDY RED](https://github.com/CANDY-LINE/candy-red)のインストールを再度行うようにしてください。

## SDカードイメージ不正

2017-07-05バージョンのRaspbianをインストールすると、`files list file for package 'qdbus' is missing final newline`というdpkgのエラーが出る事象がありました。この場合は、イメージの書き込みに失敗している可能性があります。もし、DDコマンドを利用されているときは、`conv=sync`を追加してイメージデータが全て書き込まれるようにしてください。

- 参考URL: https://www.raspberrypi.org/forums/viewtopic.php?t=187936&p=1184738

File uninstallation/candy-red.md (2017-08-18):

<!-- toc -->

# CADNY REDのアンインストール

以下のコマンドを実行すると、[CANDY RED](https://github.com/CANDY-LINE/candy-red)を削除することができます。
```bash
$ sudo npm uninstall -g --unsafe-perm candy-red
```

**ご注意：必ず`-g`と`--unsafe-perm`を指定してください**

実行すると以下のように表示されます。
```bash
[INFO] candy-red service has been uninstalled.
- abbrev@1.1.0 node_modules/candy-red/node_modules/abbrev
- addressparser@1.0.1 node_modules/candy-red/node_modules/addressparser
                  :
                (省略)
                  :
- node-red-dashboard@2.4.3 node_modules/candy-red/node_modules/node-red-dashboard
- node-red-node-serialport@0.4.4 node_modules/candy-red/node_modules/node-red-node-serialport
- ws@2.3.1 node_modules/candy-red/node_modules/ws
- candy-red@5.0.0 node_modules/candy-red
```

ただし、アンインストール実行後も`/opt/candy-red/.node-red`の内容は削除されず残されます。
また、再びインストールを行ったときは、`/opt/candy-red/.node-red/node_modules`の内容は削除されます。

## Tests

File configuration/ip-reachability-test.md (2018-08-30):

<!-- toc -->

# IP到達確認監視

** 👉[`candy-pi-lite-service v6.0.0`](https://forums.candy-line.io/t/v6-0-0)以降で対応しています **

## 概要

CANDY Pi Liteが通信中に移動するなどして圏外となった場合、通信モジュールは通信ができなくなります。その後、再び圏内に戻ると自動的に一定時間後に通信は復旧します。しかし、通信圏外になったかどうかは外部のプログラムなどからはわかりにくく、また、通信圏外時に
IPレベルでネットワークの到達確認を行うことが可能です。初期設定ではOFFになっていますので、使用する場合は下記を参照して設定を有効にしてください。

基本的な動作としては、一定時間間隔で`ping`コマンドをあらかじめ指定されたIPアドレスに対して1回発行し、その結果として応答が来れば到達確認OKとしています。もし、`ping`コマンドの応答が来ない場合は、その状態が一定時間続くかどうかを確認し、一定時間以上不到達となれば、到達確認失敗とします。この時、`PPP_PING_RESTART_IF_OFFLINE`に`0`以外の値をセットしていると、candy-pi-liteサービスの再起動を行います。到達確認が成功している間は、状態ファイル`/opt/candy-line/candy-pi-lite/__ip_reachable`が存在し続けます。

## 監視設定

IP到達確認監視を有効にするためには、インストール後に`/opt/candy-line/candy-pi-lite/environment`の内容を変更します。

```
# Network testing request interval in PPP Modem-mode (<5: disabled)
PPP_PING_INTERVAL_SEC=0

# Network reachability test destination ip address and ip version
PPP_PING_TYPE=NONE
PPP_PING_DESTINATION=1.1.1.1
PPP_PING_IP_VERSION=4
PPP_PING_OFFLINE_THRESHOLD=30
PPP_PING_RESTART_IF_OFFLINE=0
```

まずは、`ping`コマンドの実行間隔を変更します。`PPP_PING_INTERVAL_SEC`に秒数を指定します。30秒の場合は30を、1時間の場合は3600のように秒単位の値を指定します。間隔を狭めるとすぐに不到達を検知できますが、一方でオンラインの状態ではその分多くのパケット通信を行いますので、検知の重要性とパケット通信量との関係性を考慮して設定値を決めましょう。なお、この値を5秒未満にすると機能が無効になります。5秒以上の値を指定してください。

続いて、`PPP_PING_TYPE`に`TEST`と指定します。`NONE`のままでは監視が有効になりません。

さらに`ping`コマンドの宛先アドレスを次の2つの変数で指定します。
- `PPP_PING_DESTINATION` ... インターネット回線に出る場合は初期設定「1.1.1.1」で問題ありません。閉域網を利用している場合は、そのネットワークで存在するIPアドレスを指定します。またそのIPアドレスのホストは、`ping`の応答を返せる設定になっている必要があります。なお、この宛先にはIPアドレスを指定してください。ホスト名を指定すると名前を解決するための余計なパケット通信が発生するためです。また、有線LANや無線LANでアクセス可能なIPアドレスを指定することはできません。モバイルネットワーク経由でアクセスできるIPアドレスを必ず指定してください。
- `PPP_PING_IP_VERSION` ... 上記のアドレスが、IPv4のネットワークのものであれば`4`を、IPv6ネットワークのものであれば`6`をそれぞれ指定します。

`PPP_PING_OFFLINE_THRESHOLD`には、どのくらいの間`ping`コマンドに失敗すると不到達とみなすかの基準の時間を秒で指定します。

`PPP_PING_RESTART_IF_OFFLINE`には、到達確認失敗時にサービスの再起動をする場合は、`1`を、そうでない場合は`0`を指定します。

```
PPP_PING_OFFLINE_THRESHOLD ≦ PPP_PING_INTERVAL_SEC + 5
```

のように設定すると、最初の1回目の`ping`に失敗すると直ちに到達確認失敗とみなされます。

上記の5秒は、`ping`のタイムアウト時間です。この秒数は固定値となっています。

設定例は以下の通りです。

```
# Network testing request interval in PPP Modem-mode (<5: disabled)
PPP_PING_INTERVAL_SEC=30

# Network reachability test destination ip address and ip version
PPP_PING_TYPE=TEST
PPP_PING_DESTINATION=1.1.1.1
PPP_PING_IP_VERSION=4
PPP_PING_OFFLINE_THRESHOLD=60
PPP_PING_RESTART_IF_OFFLINE=0
```

これらの設定を変更した場合は、[candy-pi-lite サービスを再起動](/service/restart.md)するか、ラズパイを再起動する必要があります。

## IP到達状態を外部のプログラムなどから知るには

IP到達状態を外部のプログラムなどから知るには、実際にプログラム内でI/Oエラー（ネットワークエラー）を検知するか、あるいは下記の方法でファイルの状態を確認することにより、あらかじめ状況を知ることも可能です。

IPレベルでネットワークの到達確認に成功した時は、以下の場所に空のファイルが作成されます。

```
/opt/candy-line/candy-pi-lite/__ip_reachable
```

もし、到達失敗と判定されると、上記のファイルは削除されます。

## 監視設定を無効にするには

以下のように、`PPP_PING_TYPE`を変更します。そのほかの値はそのままでも構いません。

```
PPP_PING_TYPE=NONE
```

無効にした場合は、`/opt/candy-line/candy-pi-lite/__ip_reachable`ファイルは出現しなくなります。

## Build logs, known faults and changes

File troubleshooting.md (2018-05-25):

# トラブルシューティング

## CANDY Pi Liteが動作しない時は？(LEDが点滅しない場合)

CANDY Pi Liteは、携帯電話のネットワークに接続できている時は、[明示的にLED点滅をOFF](/configuration/led.md)にしていない限り、LEDの点滅を行います。このため、何らかの理由で携帯電話のネットワークに接続できていない時は、LEDが点滅しません。そのような場合は、以下の内容を確認の上対処を行なって、ラズパイの再起動、または、[candy-pi-lite サービスの再起動](/service/restart.md)を行なってください。

以下の確認事項や対処方法は、実際に発生した事象を元に記載しています。

1. candy-pi-lite-serviceのインストールは完了していますか？ もしかすると、candy-pi-lite サービスをインストールしていない別のSDカードを使用しているかもしれません。candy-pi-lite サービスがインストールされていない場合、モデムは自動的に起動することはありません。`systemctl status candy-pi-lite`を実施し、`(/lib/systemd/system/candy-pi-lite.service; enabled)`と表示されていることを確認しましょう。
1. USB拡張ボードを使ってUSB接続でご利用の場合、CANDY Pi Liteとラズパイは、通信用USBケーブルで正しく接続されていますか？USBのケーブルが中途半端にささっている状態になっていたりすると正しく動作しないので、CANDY Pi LiteやラズパイのUSB接続がしっかりささっているかどうか確認しましょう。
1. NTT DOCOMOの電波の圏内ですか？ [こちら](https://www.nttdocomo.co.jp/support/area/)のサイトからFOMA/LTEのサービスエリアを確認し、サービスエリア圏内であることを確認しましょう。また、[ネットワーク状態の表示](ネットワーク状態の表示.md)コマンドを利用すれば、電波が圏外かどうかがわかりますから試してみると良いでしょう。あるいはまた、FOMA/LTE対応の携帯電話をお持ちであれば、FOMA/LTEの電波が圏内であることを確認してみましょう。
1. CANDY Pi Liteにアンテナは正しく接続されていますか？ モデムは、電源が十分供給されていてもアンテナが接続されていないと起動することができません。モデムに接続するアンテナケーブルとアンテナ本体が、外れることなく取り付けられていることを確認しましょう。
1. ラズパイに供給する機器側からは十分な電力が供給できていますか？ CANDY Pi Liteが動作するためには、ラズパイに加えてより多くの電力が必要になります。もしかするとUSBバスパワーを供給する機器側のUSBポートは、電力が十分ではないかもしれません。もしうまく動作しない場合は、別のUSBポートにつなぎ変えたり、別のUSB電源用意したり、あるいはACアダプターをお試しください。
1. ラズパイに電源供給するために使用しているUSBケーブルは正しく動作していますか？ USBケーブルの商品の種類や使用状態によっては、CANDY Pi Liteが動作するために必要な電力をラズパイに伝えられていない可能性もあります。他のUSBケーブルをご利用になるか、ACアダプターを利用することも検討してください。
1. SIMカードが入っているのに、動作しなかったり、`sudo candy sim show`を実行してみても、SIMが認識されておらず、`SIM_STATE_ABSENT`と出てしまったりしていますか？　そのような場合は、CANDY Pi Lite本体やSIMカードに、ホコリやゴミなどが紛れてしまっているかもしれません。[ブロワー（またはブロアー）](https://www.amazon.co.jp/gp/search/ref=a9_asi_1?rh=i%3Aelectronics%2Cn%3A3210981%2Ck%3Aブロアー&keywords=ブロアー&ie=UTF8&qid=1474555047)や[エアダスター](https://www.amazon.co.jp/s/ref=nb_sb_noss_1?__mk_ja_JP=カタカナ&url=search-alias%3Doffice-products&field-keywords=エアダスター&rh=n%3A86731051%2Ck%3Aエアダスター)などでホコリやゴミを取り除いてから、確認してみましょう。
1. SORACOM Connect Air SIMカードをお使いですか？ その場合は、回線が`使用中`と表示されているか[ユーザーコンソール](https://console.soracom.io/)で確認しましょう。休止中になっていると、契約中の有効なSIMカードであっても接続することができません。
1. APNの情報はあっていますか？SIMカード契約先だけでなく、回線のプランもAPNの設定とあっていることを確認しましょう。

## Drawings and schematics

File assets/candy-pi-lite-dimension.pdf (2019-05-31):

6

4

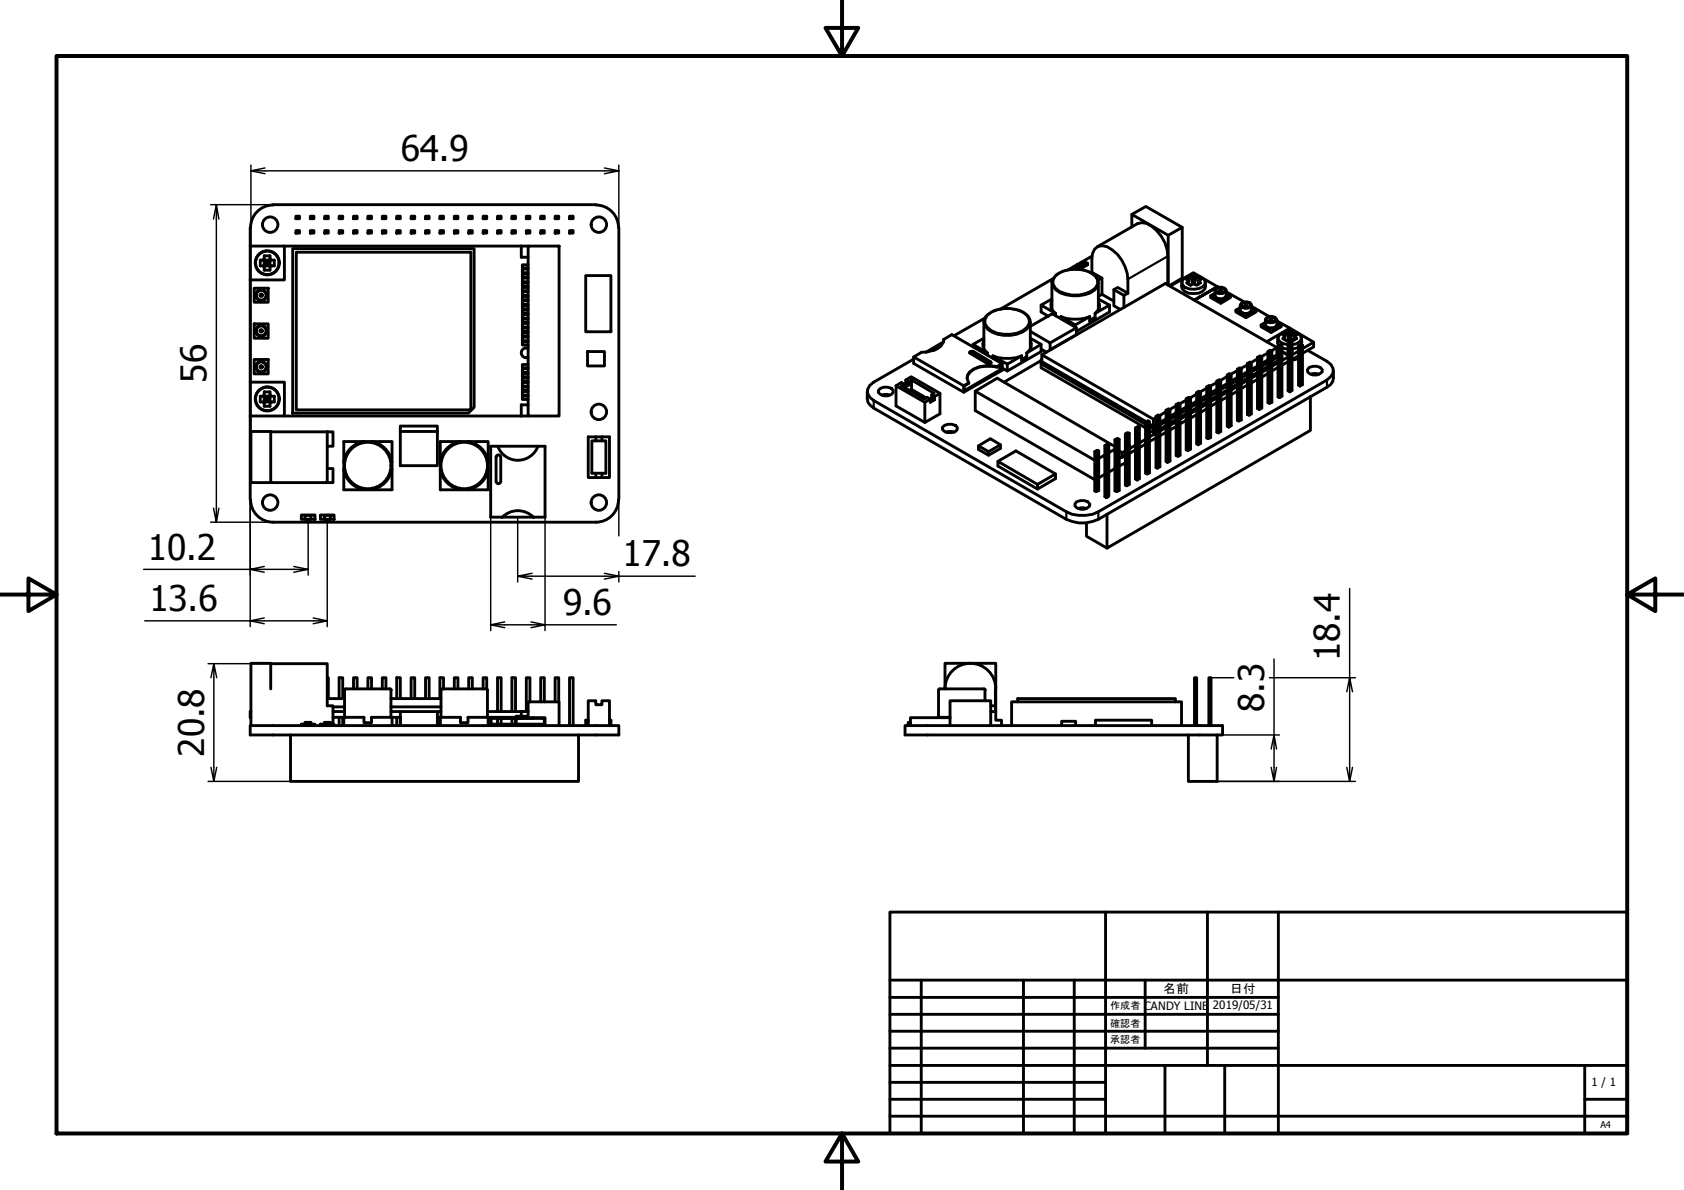
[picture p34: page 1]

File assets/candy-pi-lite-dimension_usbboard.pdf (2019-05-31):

8

5

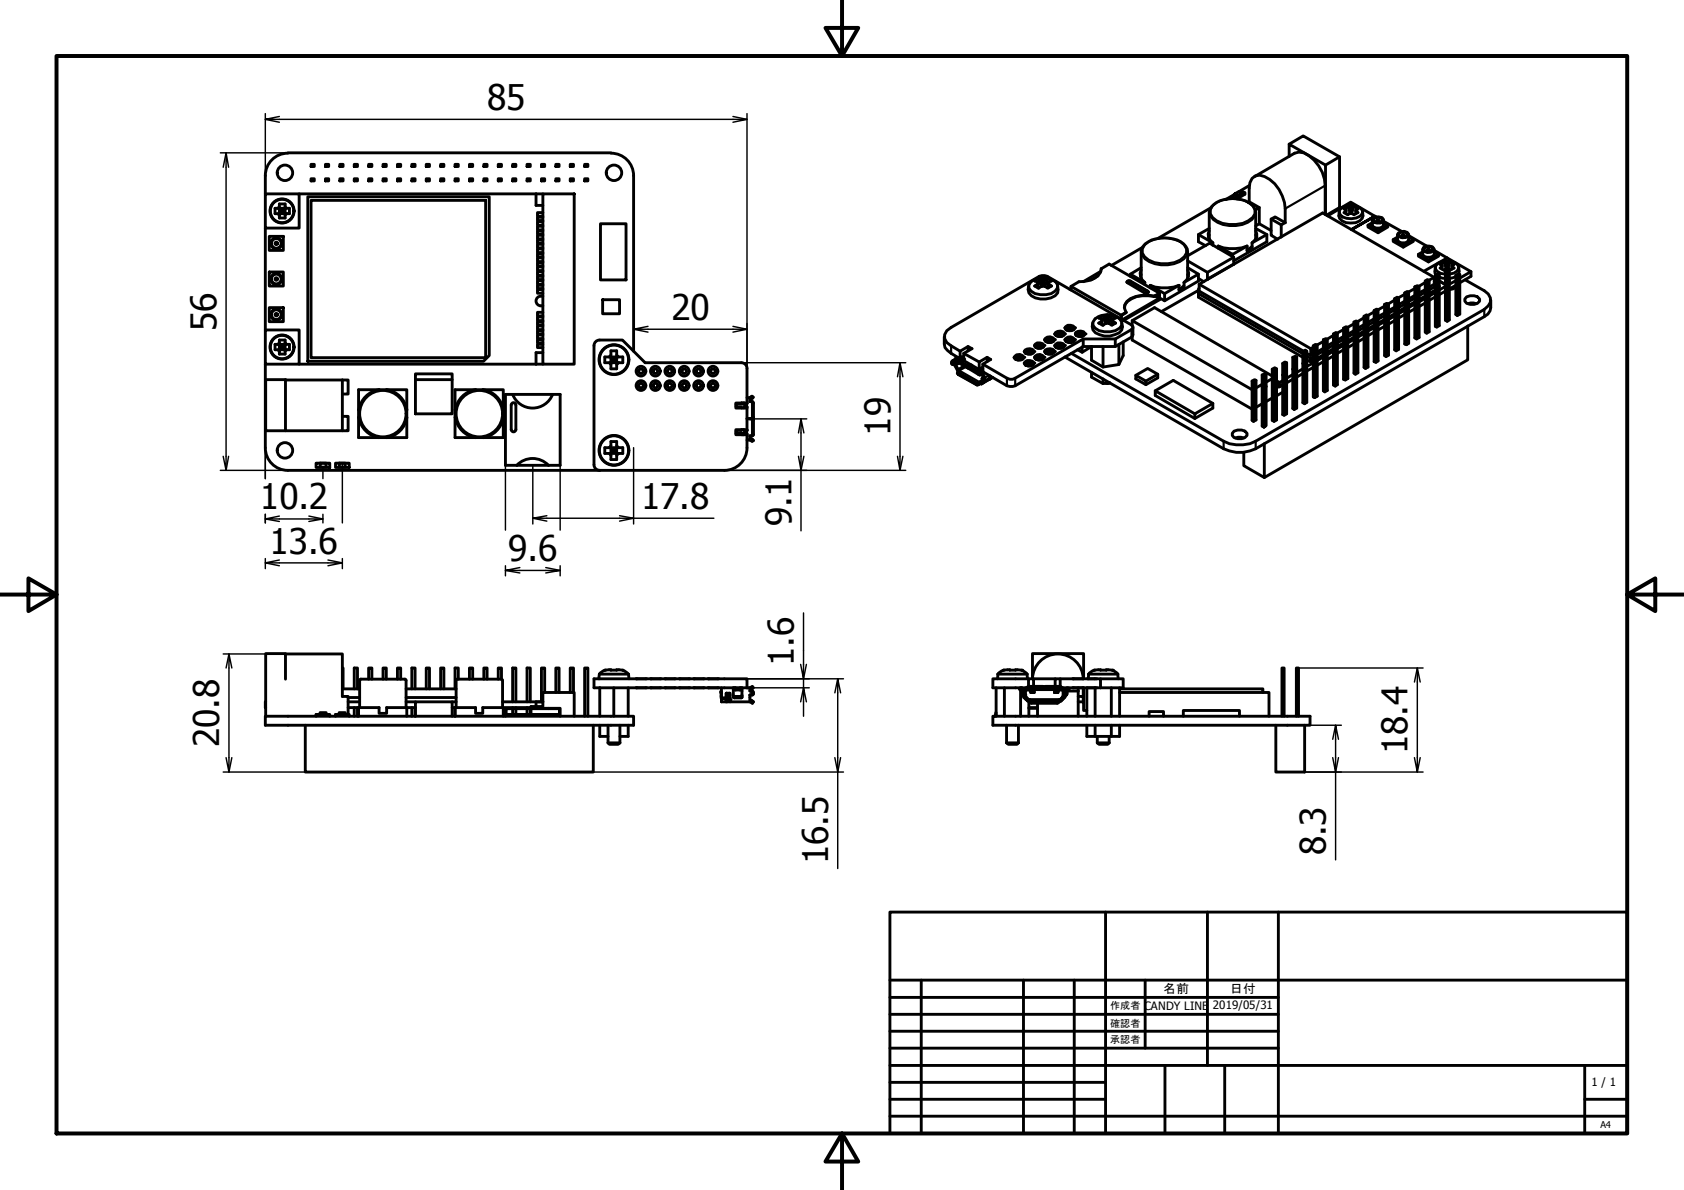
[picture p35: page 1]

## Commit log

2017-08-14 Remove missing filter
2017-08-18 Add pages for assembly instructions
2017-08-18 Add a new chapter for LED and remove environment variables
2017-08-19 Update led description
2017-08-20 Describe USB extension board
2017-08-28 Add ASUS Tinker Board GPIO mappings as well
2017-11-28 Add a reference to a blog post describing how to use preinstalled OS image for CANDY Pi Lite board
2018-01-18 Use ASUS Tinker Board rather than Tinker Board
2018-01-30 Describe how to remove antenna cables
2018-02-06 Annotate DC connector use for ATB-S
2018-02-06 Describe supporting Raspberry Pi only
2018-02-06 Refer to ASUS Tinker Board S as well as ASUS Tinker Board (not S)
2018-02-22 Clarify the operating temperature description (Ta)
2018-03-07 Add a new page describing main board appearances for CANDY Pi Lite 3G and LTE model
2018-04-12 Update DC jack notice regarding ASUS Tinker Board S
2018-04-12 Add a description to mention the number of required 3G antennas
2018-04-27 Add a new description for router settings on Raspberry Pi with CANDY Pi Lite/+
2018-04-27 Add descriptions for GNSS antennas and cables and USB cables
2018-05-12 Add a new page for assembling CANDY Pi Lite+
2018-05-12 Add description regarding SPI
2018-05-24 Append descriptions on LED ticker patterns
2018-05-31 Add a new section to describe how to check if the USB extension board works properly
2018-11-29 Describe how to purchase 3G/4G LTE antenna and cable set
2019-02-13 Illustrate how to insert a SIM card into CANDY Pi Lite
2019-05-31 Add 3D data
    [candy-pi-lite-dimension.dxf, candy-pi-lite-dimension.stp, candy-pi-lite-dimension_usbboard.dxf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]
2020-08-03 Update gpio.md
    現在USB拡張ボードのGPIOはサポートしていないため記載を削除しました。
